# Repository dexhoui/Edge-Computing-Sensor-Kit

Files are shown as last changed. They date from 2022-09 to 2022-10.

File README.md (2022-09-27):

# **ECSK:** **E**deg **C**omputing **S**ensor **K**it
**Editor:** Bohao Chu, **Date:** 09.09.2022, **Email:** bohao.chu@qq.com

**Supervisor:**  Fuyin Wei, Fei Xiang, Bernd Noche

## **BASIC**
`git clone --recurse-submodules https://github.com/dexhoui/Edge-Computing-Sensor-Kit.git ./`
> git clone --recurese-submodules = git submodule init && git submodule update

`git submodule update --remote` update submodule from branch.

## **INTRODUCTION**
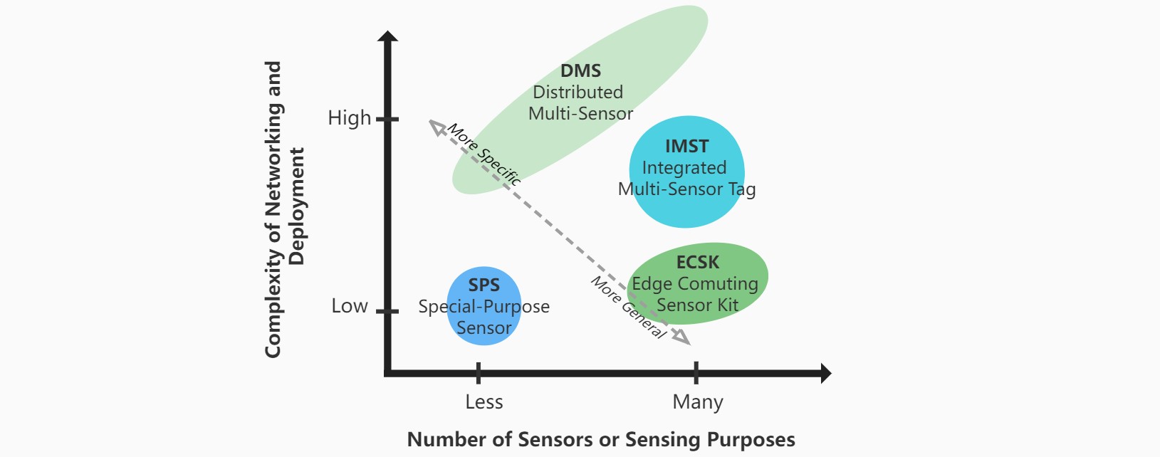
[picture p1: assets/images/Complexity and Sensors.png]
CM4 IO Board

In traditional IoT scenarios, **Specific-Purpose Sensor (SPS)** or **Distributed Multi-Sensor (DMS)** are usually deployed directly on different locations or objects to sense diverse purposes, However, the number of sensing purposes always conflict with the complexity of networking and deployment. **Integrated Multi-Sensor Tag (IMST)** alleviates this problem, such as Texas Instruments <i>SimpleLink SensorTag</i> and Laput's <i>Synthetic Sensors</i>, with multiple sensors integrated on a small board to indirectly monitor a large context,  without direct instrumentation of objects. But due to the limited computing power of IMST, a large amount of raw data still needs to be sent to the remote server for processing through wireless technologies such as <i>Bluetooth</i> or <i>WiFi</i> , which may lead to processing delays, data leakage or intrusion.

In this work, we explore the concept of **Edge Computing Senosr Kit (ECSK)** based on the former work. We designed a new type of hardware that integrates several different types of sensors, including a camera and a microphone, on a small board, while adding a powerful processor and tpu, which allows algorithmic models and applications to run directly on the it instead of on a remote server. Each sensor has a task channel of its own, and multiple sensors can independently perform data sampling and feature extraction with concurrency. Feature data from different sensor channels are used to achieve real-time recognition of general activities in the environment (e.g., robotic arm movement) by a **Machine Learning (ML)** based multi-sensor **Information Fusion** algorithm. 

## **HARDWARE**
We designed a new type of hardware that integrates several different types of sensors, including a camera and a microphone, on a small board, while adding a powerful processor and tpu, which allows algorithmic models and applications to run directly on the it instead of on a remote server.

Enter our <a href="./hardware/">Hardware Folder</a> to konw how to use it
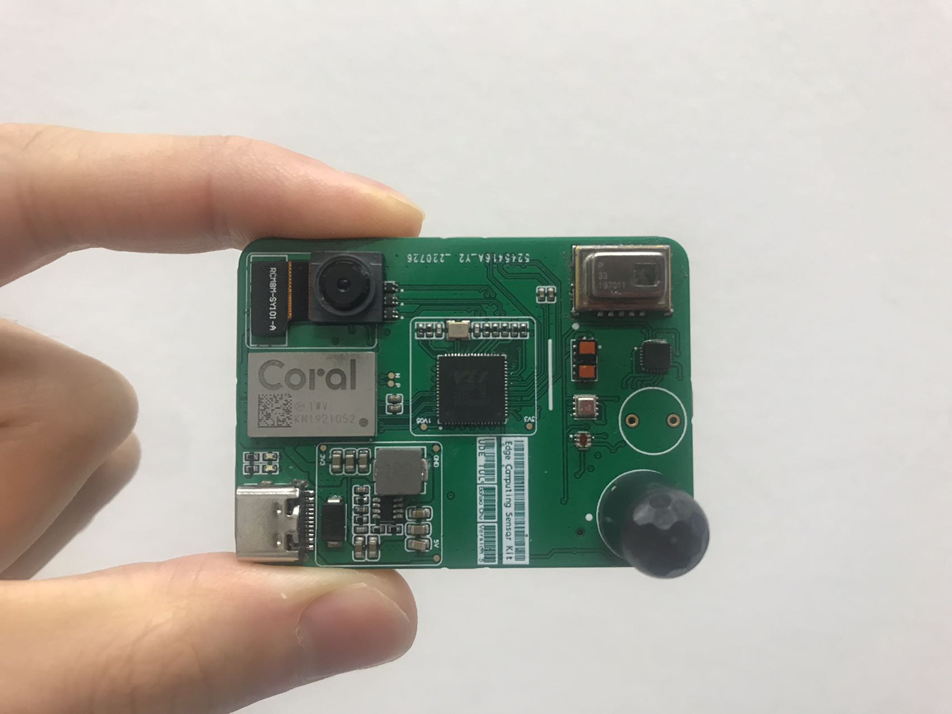
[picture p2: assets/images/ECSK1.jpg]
ECSK


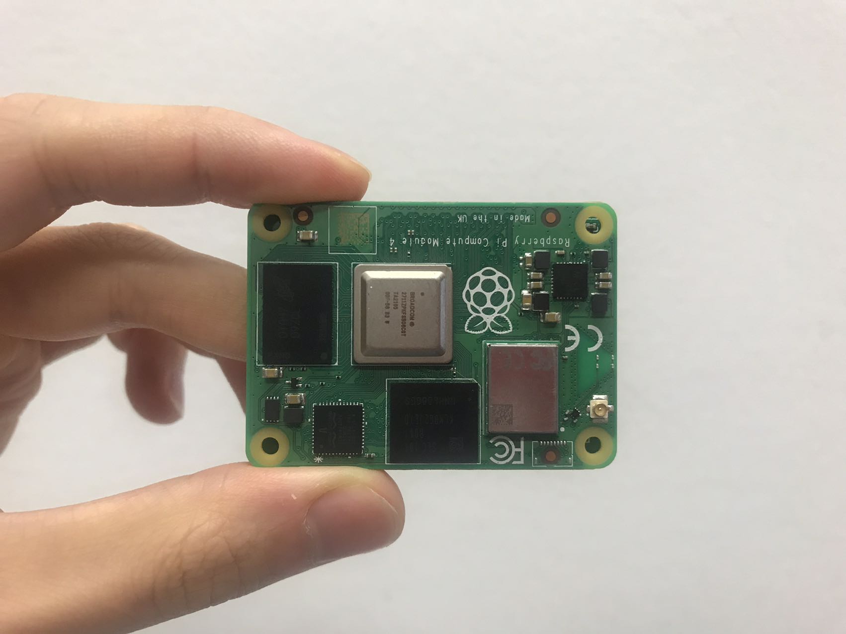
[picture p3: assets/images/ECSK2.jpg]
ECSK

<table border="1" style="text-align: center;">
    <tr>
        <td><b>Module</b></td>
        <td><b>Model</b></td> 
        <td><b>Protocol</b></td>
        <td><b>Frequency</b></td> 
        <td><b>Channel</b></td>
        <td><b>Description</b></td>
    </tr>
    <tr>
        <td><a href="https://coral.ai/products/accelerator-module">Coral</a></td>
        <td>G313</td> 
        <td>USB3.0</td> 
        <td>4TOPS</td>
        <td>1</td>
        <td>The Accelerator Module is a surface-mounted module that includes the Edge TPU and its own power control. It provides accelerated inferencing for TensorFlow Lite models on your custom PCB hardware.</td>
    </tr>
    <tr>
        <td>CM4</td>
        <td>ARM</td> 
        <td>/</td> 
        <td>Foo</td>
        <td>Foo</td>
        <td>/</td>
    </tr>
    <tr>
        <td>Microphone</td>
        <td><a href="https://learn.adafruit.com/adafruit-i2s-mems-microphone-breakout/raspberry-pi-wiring-test">INMP441</a></td> 
        <td>I2S</td> 
        <td>15K</td>
        <td>1</td>
        <td>1</td>
    </tr>
    <tr>
        <td>Motion Processing Unit</td>
        <td><a href="https://invensense.tdk.com/products/motion-tracking/9-axis/mpu-9250/">MPU9250</a></td> 
        <td>I2C</td> 
        <td>1K</td>
        <td>3</td>
        <td>The MPU-9250 is the company’s second generation 9-axis Motion Processing Unit™ for smartphones, tablets, wearable sensors, and other consumer markets.</td>
    </tr>
    <tr>
        <td>Laser</td>
        <td><a href="https://www.sparkfun.com/products/14722">VL53L1X</a></td> 
        <td>I2C</td> 
        <td>20</td>
        <td>1</td>
        <td>The MPU-9250 is the company’s second generation 9-axis Motion Processing Unit™ for smartphones, tablets, wearable sensors, and other consumer markets.</td>
    </tr>
    <tr>
        <td>EYE</td>
        <td><a href="https://www.sparkfun.com/products/14607">AMG8833</a></td> 
        <td>I2C</td> 
        <td>20</td>
        <td>1</td>
        <td>The MPU-9250 is the company’s second generation 9-axis Motion Processing Unit™ for smartphones, tablets, wearable sensors, and other consumer markets.</td>
    </tr>
    <tr>
        <td>BME</td>
        <td><a href="https://www.raspberrypi-spy.co.uk/2016/07/using-bme280-i2c-temperature-pressure-sensor-in-python/">BME280</a></td> 
        <td>I2C</td> 
        <td>20</td>
        <td>1</td>
        <td>The MPU-9250 is the company’s second generation 9-axis Motion Processing Unit™ for smartphones, tablets, wearable sensors, and other consumer markets.</td>
    </tr>
    <tr>
        <td>Color</td>
        <td><a href="https://www.sparkfun.com/products/12829">ISL29125</a></td> 
        <td>I2C</td> 
        <td>20</td>
        <td>1</td>
        <td>The MPU-9250 is the company’s second generation 9-axis Motion Processing Unit™ for smartphones, tablets, wearable sensors, and other consumer markets.</td>
    </tr>
    <tr>
        <td>ADC</td>
        <td><a href="https://www.sparkfun.com/products/15334">ADS1015</a></td> 
        <td>ADC</td> 
        <td>3.3K</td>
        <td>1</td>
        <td>The MPU-9250 is the company’s second generation 9-axis Motion Processing Unit™ for smartphones, tablets, wearable sensors, and other consumer markets.</td>
    </tr>
    <tr>
        <td>PIR</td>
        <td><a href="https://eu.mouser.com/ProductDetail/Panasonic-Industrial-Devices/AMN21111?qs=mTeSeKeuVA47b9orPGfrSw%3D%3D">AMN2111J</a></td> 
        <td>ADC</td> 
        <td>3.3K</td>
        <td>1</td>
        <td>The MPU-9250 is the company’s second generation 9-axis Motion Processing Unit™ for smartphones, tablets, wearable sensors, and other consumer markets.</td>
    </tr>
    <tr>
        <td>EMI</td>
        <td><a href="https://www.mouser.de/ProductDetail/Bourns/RLB0913-104K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">100MH</a></td> 
        <td>ADC</td> 
        <td>3.3K</td>
        <td>1</td>
        <td>The MPU-9250 is the company’s second generation 9-axis Motion Processing Unit™ for smartphones, tablets, wearable sensors, and other consumer markets.</td>
    </tr>
    <tr>
        <td>Camera</td>
        <td><a href="https://www.raspberrypi.com/products/camera-module-v2/">IMX219</a></td> 
        <td>CSI</td> 
        <td>80</td>
        <td>1</td>
        <td>The MPU-9250 is the company’s second generation 9-axis Motion Processing Unit™ for smartphones, tablets, wearable sensors, and other consumer markets.</td>
    </tr>
</table>

## **SOFTWARE**
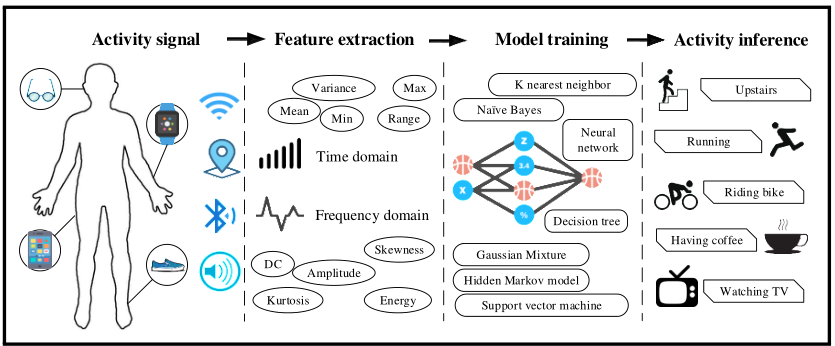
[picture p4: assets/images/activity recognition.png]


## **SENSOR EDGE**
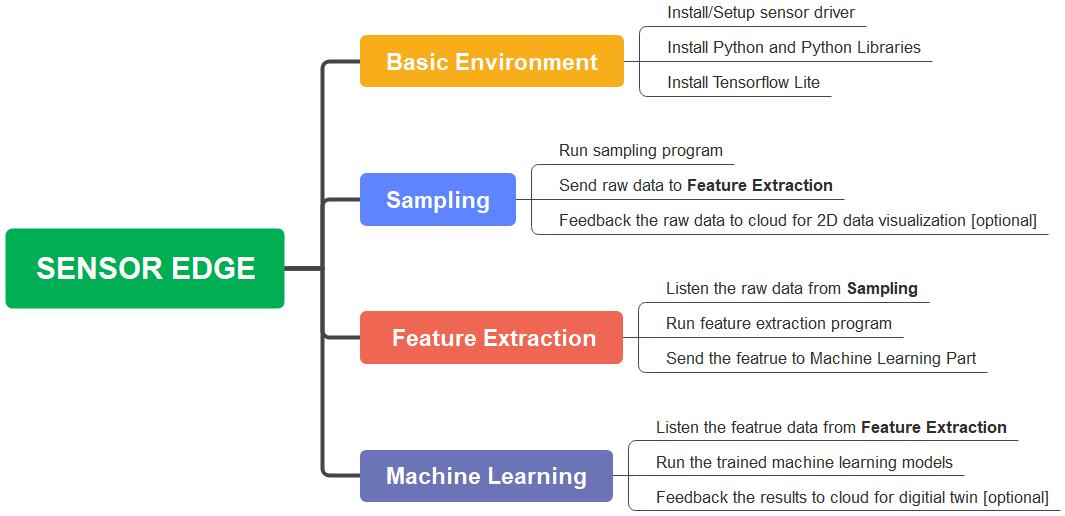
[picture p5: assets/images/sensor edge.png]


## **SENSOR SERVER**
ECSK

## **SENSOR APP**
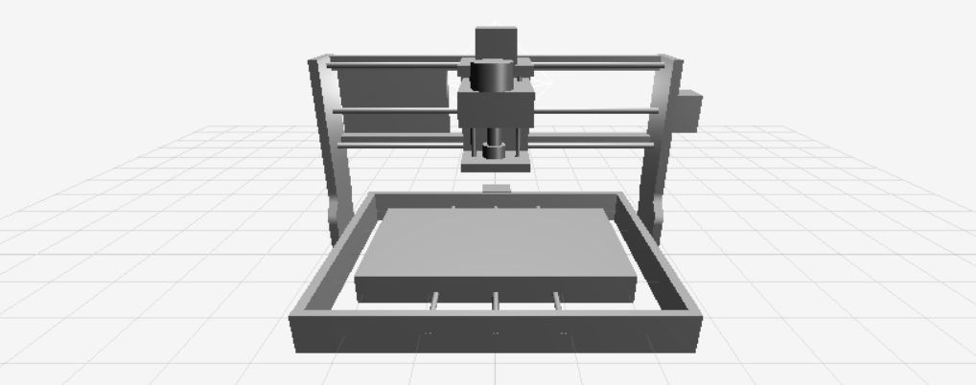
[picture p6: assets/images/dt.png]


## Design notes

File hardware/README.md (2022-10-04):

# **Hardware**
**Editor:** Bohao Chu, **Date:** 23.09.2022, **Email:** bohao.chu@qq.com

**Supervisor:**  Fuyin Wei, Fei Xiang, Bernd Noche

The **Edge Computing Sensor Kit Hardware** is consist of two parts, **Compute Module 4** and **Sensor Kit**. The Compute Module 4 can be bought in stores, and the Sensor Kit can be got via PCB Producer by providing our PCB file.

We designed our Sensor Kit via Altium Designer 22,  Without going into too much detail about the design of the PCB, I have made the  [source project](/hardware/printed%20circuit%20board/) available.

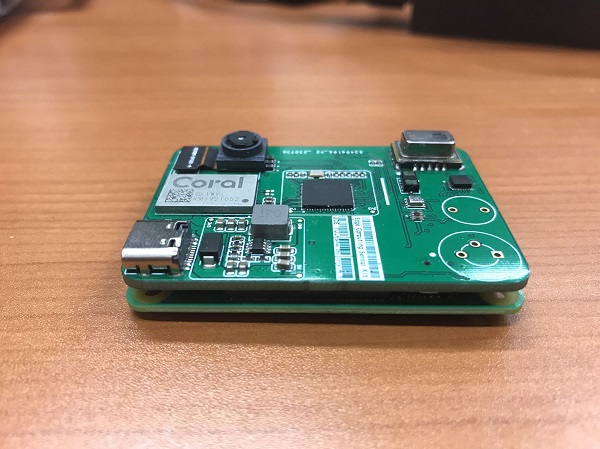
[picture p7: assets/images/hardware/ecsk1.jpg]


## **Compute Module 4**
In this chapter, I will discribe how to use it. 
[More information about Compute Module 4](https://www.raspberrypi.com/products/compute-module-4/?variant=raspberry-pi-cm4001000)

### **A. Flashing new OS ot Compute Module 4 eMMC**
We have to use an io board for flashing operation system. The requirementes for flashing the Compute Module 4 eMMC as follows:

- [Compute Module 4](https://www.raspberrypi.com/products/compute-module-4/?variant=raspberry-pi-cm4001000)
- [IO Board](https://www.waveshare.com/wiki/CM4-IO-BASE-A) ( other io boards are also available. )
- [Windows Installer](https://github.com/raspberrypi/usbboot/raw/master/win32/rpiboot_setup.exe) ( download it and insatll it, it may need to wait a while.)
- [Raspberry Pi Imager](https://downloads.raspberrypi.org/imager/imager_latest.exe)( download it and insatll it. )

#### **A1. Install Compute Module 4 on IO Board**
We used [Waveshare CM4 IO Board](https://www.waveshare.com/wiki/CM4-IO-BASE-A) as our IO board.
Ensure the Compute Module is fitted correctly installed on the IO board. It should lie flat on the IO board.

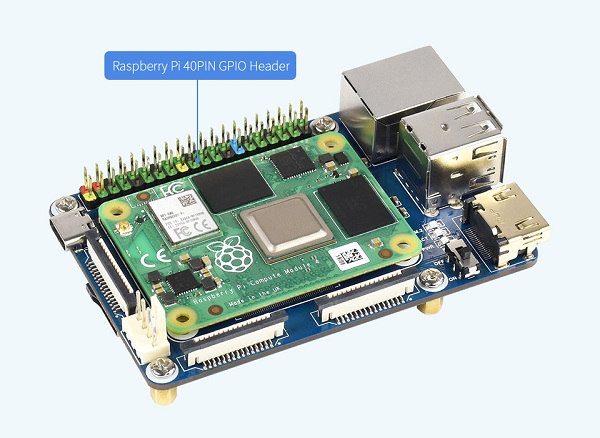
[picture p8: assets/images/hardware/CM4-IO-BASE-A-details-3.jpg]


#### **A2. Setup IO Board to USB model**
After the CM4 was installed on the IO Board, we should set IO Board to USB model by setting the switch to **ON**. Then plug your host PC USB into the USB SLAVE port. Supply power to the board.

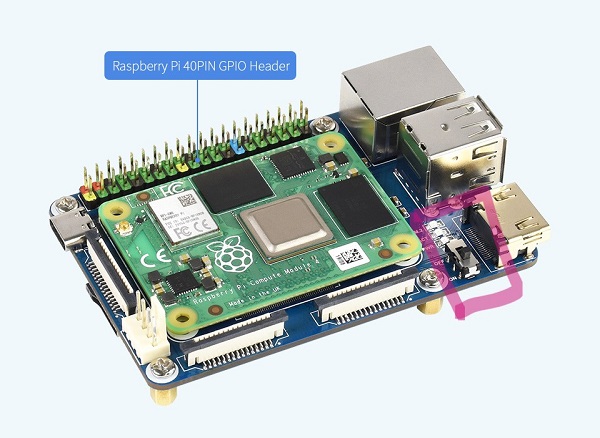
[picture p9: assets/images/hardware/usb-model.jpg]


#### **A3. Open rpiboot on windows**
This software is used to install the drivers and boot tool. After a few seconds, the Compute Module eMMC will pop up under Windows as a disk (USB mass storage device).

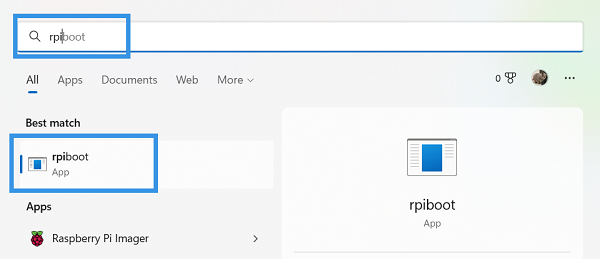
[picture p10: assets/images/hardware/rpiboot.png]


It may need to **wait a while**. *If you get stuck here, unplug the USB and then plug it into the PC again.*

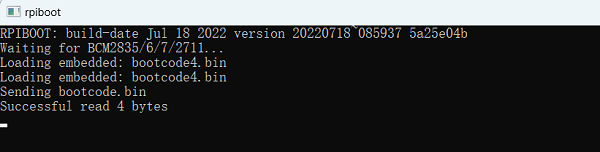
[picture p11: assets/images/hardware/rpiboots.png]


Then the CM4 will pop under windows as a **disk**.

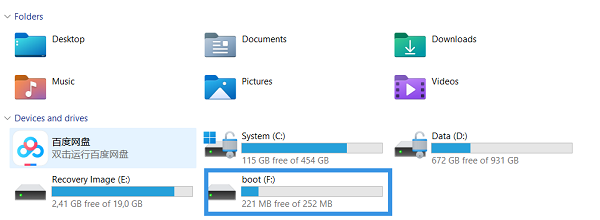
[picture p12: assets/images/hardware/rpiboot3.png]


#### **A4. Open RPI Imager on windows**
First, click the **CHOOSE OS** button, then select the **Raspberry Pi OS(other)** button, then choose the **Raspberry Pi OS(64-bit)** or **Raspberry Pi OS Lite(64-bit)**. Here I choosed the **Raspberry Pi OS(64-bit)** without Deskpot.

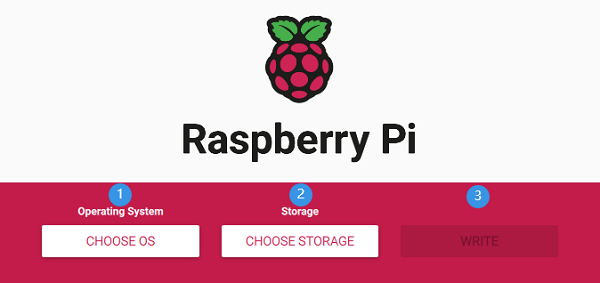
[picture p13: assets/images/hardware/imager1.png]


Second, click the **CHOOSE STORAGE**  button, then choose **RPI-MSD-0001** item.

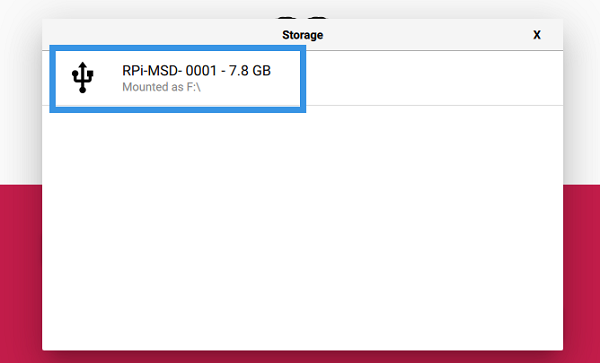
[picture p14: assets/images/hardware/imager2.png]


Third, click the **Setting**  button.
1. Select **Set hostname** and input "sensor".
2. Select **Enable SSH** and **use password authentication**.
3. Select **Set username and password**. set username to "pi", password to "123456". 
4. **Configure wireless LAN**, input name and password of WiFi. Set wireless LAN country as DE(Germany).
5. Select **Set locale settings**, set Time zone to "Europe/Berlin", Keyboard layout to "us".
6. Select **Eject media when finished** and **Enable telemetry**.

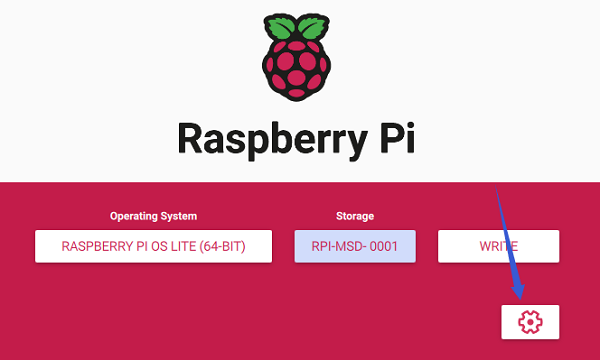
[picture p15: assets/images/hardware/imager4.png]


Finally, Click the **WRITE** button and choose **YES**, then wait a while.

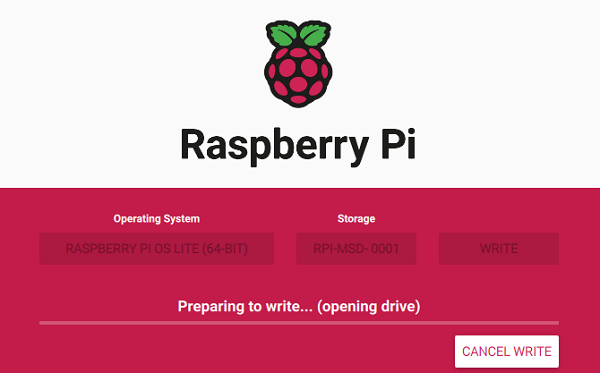
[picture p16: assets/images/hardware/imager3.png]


## **Sensor Kit**
After the OS was flashed into CM4, then uninstall CM4 from the io board, and install it on our edge computing sensor kit. Then supply 5V/3A (Not less than 2A) power to our Sensor Kit.

### **A. Config the WiFi**
We did not add the ethernet port to our sensor kit due to the space limitation and the Internet is not necesarry, but you can use the WiFi of CM4 to connect the Internet. You can use this way to change the WiFi SSID and WiFi Password so that the ECSK can be applied on anywhere with wifi.

1. Install the CM4 on IO board.

2. Setup IO Board to USB model and connect the USB to the PC, and then supply power to the IO Board.

3. Open rpiboot on windows, the CM4 will pop up under Windows as a disk. 

4. Enter this disk and make a new file named "wpa_supplicant.conf", and edit it with the following content.
>
    ctrl_interface=DIR=/var/run/wpa_supplicant GROUP=netdev
    update_config=1
    network={
        ssid="WiFi SSID"
        psk="WiFi Password"
    }
>

5. Then install CM4 on oure Sensor Kit and start up. After a while, it will automatically connect to the WiFi you have configured.

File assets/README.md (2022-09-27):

# ASSETS
**Editor:** Bohao Chu, **Date:** 24.09.2022, **Email:** bohao.chu@qq.com

**Supervisor:**  Fuyin Wei, Fei Xiang, Bernd Noche

## Images

The most of image in this project will be uploaded, but the most videos in this porject will not be uploaded, you can find them in Google Driver. For more information, please contact Mr.Fei Xiang.

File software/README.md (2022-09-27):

# **Software**
**Editor:** Bohao Chu, **Date:** 20.09.2022, **Email:** bohao.chu@qq.com

**Supervisor:**  Fuyin Wei, Fei Xiang, Bernd Noche

The **Edge Computing Sensor Kit Software** is consist of three parts, **[Sensor Server](/software/sensor-server/)**, **[Sensor Edge](/software/sensor-edge/)**, and **[Sensor Application](/software/sensor-application/)**. 

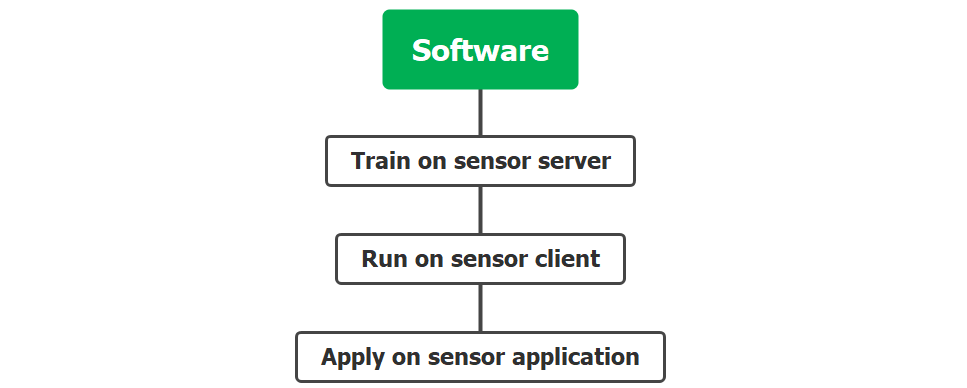
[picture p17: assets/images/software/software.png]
CM4 IO Board


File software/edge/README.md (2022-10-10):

# **SENSOR EDGE**
**Editor:** Bohao Chu, **Date:** 20.09.2022, **Email:** bohao.chu@qq.com

**Supervisor:**  Fuyin Wei, Fei Xiang, Bernd Noche

We need to do some initialization before runing our embedded program and machine learning model.
CM4 IO Board

## **BASIC ENVIRONMENT**
We recommend to install the following softwares before starting this section.

[Advance IP Scanner](https://download.radmin.com/download/files/Radmin_3.5.2.1_EN.zip) for getting the IP of ECSK.

[PUTTY](https://the.earth.li/~sgtatham/putty/latest/w64/putty-64bit-0.77-installer.msi) for connecting the ECSK via SSH. 

We recommend that the following two commands before executing any installation to ensure proper installation of the latest software.

- `sudo apt update`

- `sudo apt upgrade`

Install some common software. Some software requires your confirmation, so type Y when prompted.

- `sudo apt install git vim i2c-tools python3-pip portaudio19-dev libsndfile1`

Download source code.

- `git clone --branch edge https://github.com/dexhoui/Edge-Computing-Sensor-Kit.git ~/edge`

Install some python libraries.
- `sudo pip3 install smbus sparkfun-qwiic serial pyaudio matplotlib librosa tflite-runtime adafruit-python-shell`

### **A. Sensors Driver**
<table border="1" style="text-align: center;">
    <tr>
        <td><b>Module</b></td>
        <td><b>Model</b></td> 
        <td><b>Protocol</b></td>
        <td><b>Frequency</b></td> 
        <td><b>Channel</b></td>
        <td><b>Description</b></td>
    </tr>
    <tr>
        <td><a href="https://coral.ai/products/accelerator-module">Coral</a></td>
        <td>G313</td> 
        <td>USB3.0</td> 
        <td>4TOPS</td>
        <td>1</td>
        <td>The Accelerator Module is a surface-mounted module that includes the Edge TPU and its own power control. It provides accelerated inferencing for TensorFlow Lite models on your custom PCB hardware.</td>
    </tr>
    <tr>
        <td>CM4</td>
        <td>ARM</td> 
        <td>/</td> 
        <td>Foo</td>
        <td>Foo</td>
        <td>/</td>
    </tr>
    <tr>
        <td>Microphone</td>
        <td><a href="https://learn.adafruit.com/adafruit-i2s-mems-microphone-breakout/raspberry-pi-wiring-test">INMP441</a></td> 
        <td>I2S</td> 
        <td>15K</td>
        <td>1</td>
        <td>1</td>
    </tr>
    <tr>
        <td>Motion Processing Unit</td>
        <td><a href="https://invensense.tdk.com/products/motion-tracking/9-axis/mpu-9250/">MPU9250</a></td> 
        <td>I2C</td> 
        <td>1K</td>
        <td>3</td>
        <td>The MPU-9250 is the company’s second generation 9-axis Motion Processing Unit™ for smartphones, tablets, wearable sensors, and other consumer markets.</td>
    </tr>
    <tr>
        <td>Laser</td>
        <td><a href="https://www.sparkfun.com/products/14722">VL53L1X</a></td> 
        <td>I2C</td> 
        <td>20</td>
        <td>1</td>
        <td>The MPU-9250 is the company’s second generation 9-axis Motion Processing Unit™ for smartphones, tablets, wearable sensors, and other consumer markets.</td>
    </tr>
    <tr>
        <td>EYE</td>
        <td><a href="https://www.sparkfun.com/products/14607">AMG8833</a></td> 
        <td>I2C</td> 
        <td>20</td>
        <td>1</td>
        <td>The MPU-9250 is the company’s second generation 9-axis Motion Processing Unit™ for smartphones, tablets, wearable sensors, and other consumer markets.</td>
    </tr>
    <tr>
        <td>BME</td>
        <td><a href="https://www.raspberrypi-spy.co.uk/2016/07/using-bme280-i2c-temperature-pressure-sensor-in-python/">BME280</a></td> 
        <td>I2C</td> 
        <td>20</td>
        <td>1</td>
        <td>The MPU-9250 is the company’s second generation 9-axis Motion Processing Unit™ for smartphones, tablets, wearable sensors, and other consumer markets.</td>
    </tr>
    <tr>
        <td>Color</td>
        <td><a href="https://www.sparkfun.com/products/12829">ISL29125</a></td> 
        <td>I2C</td> 
        <td>20</td>
        <td>1</td>
        <td>The MPU-9250 is the company’s second generation 9-axis Motion Processing Unit™ for smartphones, tablets, wearable sensors, and other consumer markets.</td>
    </tr>
    <tr>
        <td>ADC</td>
        <td><a href="https://www.sparkfun.com/products/15334">ADS1015</a></td> 
        <td>ADC</td> 
        <td>3.3K</td>
        <td>1</td>
        <td>The MPU-9250 is the company’s second generation 9-axis Motion Processing Unit™ for smartphones, tablets, wearable sensors, and other consumer markets.</td>
    </tr>
    <tr>
        <td>PIR</td>
        <td><a href="https://eu.mouser.com/ProductDetail/Panasonic-Industrial-Devices/AMN21111?qs=mTeSeKeuVA47b9orPGfrSw%3D%3D">AMN2111J</a></td> 
        <td>ADC</td> 
        <td>3.3K</td>
        <td>1</td>
        <td>The MPU-9250 is the company’s second generation 9-axis Motion Processing Unit™ for smartphones, tablets, wearable sensors, and other consumer markets.</td>
    </tr>
    <tr>
        <td>EMI</td>
        <td><a href="https://www.mouser.de/ProductDetail/Bourns/RLB0913-104K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">100MH</a></td> 
        <td>ADC</td> 
        <td>3.3K</td>
        <td>1</td>
        <td>The MPU-9250 is the company’s second generation 9-axis Motion Processing Unit™ for smartphones, tablets, wearable sensors, and other consumer markets.</td>
    </tr>
    <tr>
        <td>Camera</td>
        <td><a href="https://www.raspberrypi.com/products/camera-module-v2/">IMX219</a></td> 
        <td>CSI</td> 
        <td>80</td>
        <td>1</td>
        <td>The MPU-9250 is the company’s second generation 9-axis Motion Processing Unit™ for smartphones, tablets, wearable sensors, and other consumer markets.</td>
    </tr>
</table>

#### **A1. Microphone Driver**

**First**, install INMP441 Driver, execute the following commands sequentially in Terminal.
1. `cd ~/edge/tools/ && sudo python3 i2smic.py`
2. Please type y when prompt `"Auto load module at boot"?`
3. Please type y when prompt `"REBOOT NOW? [Y/n]"`
4. Connect it again via ssh.

**Second**, Test the INMP441 Driver.
1. `arecord -l`
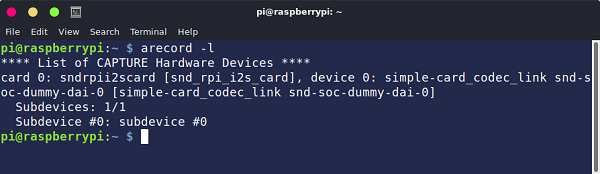
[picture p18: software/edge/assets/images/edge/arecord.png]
- 

2. `arecord -D plughw:0 -c1 -r 48000 -f S32_LE -t wav -V mono -v file.wav`
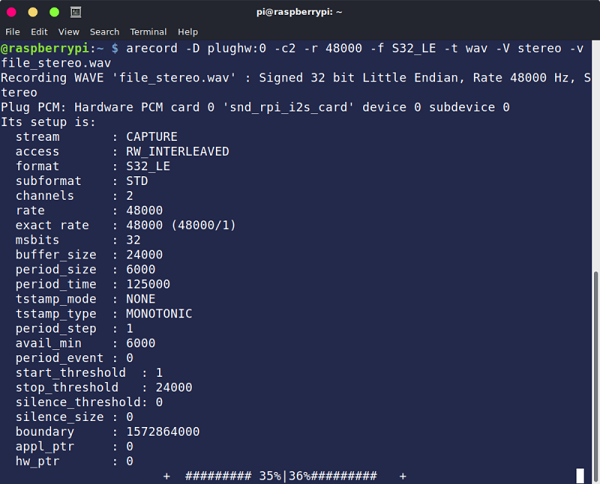
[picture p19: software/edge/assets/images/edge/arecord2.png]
- 

3. `rm file.wav`

4. `python3 ~/edge/source/drivers/micDriver.py`
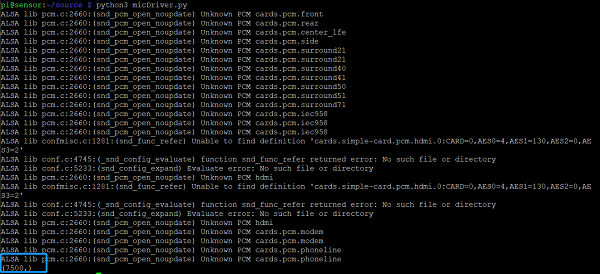
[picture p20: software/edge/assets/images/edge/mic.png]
MIC
- 

#### **A2. Motion Processing Unit**
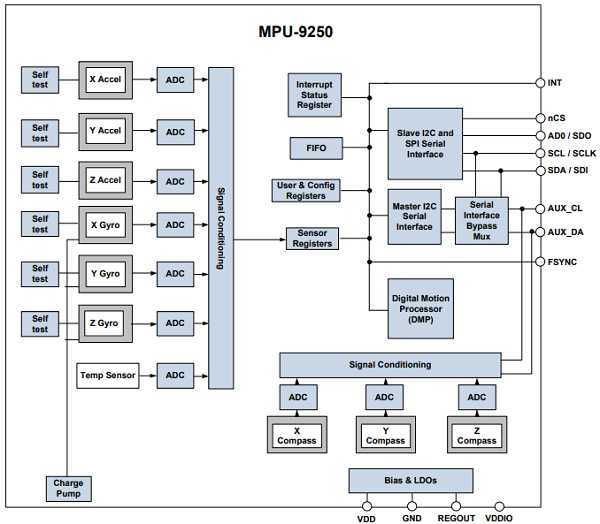
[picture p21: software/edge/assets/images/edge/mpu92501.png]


**First**, Open I2C1 interface of CM4.
1. `sudo raspi-config`
2. Select `3 Interface Options` and type *Enter* key.
3. Select `I5 I2C` and type *Enter* key.
4. Select `YES` via *Tab* Key
5. Select `Finish` via *Tab* Key
3. `sudo reboot` and then connect it again via ssh.

**Second**, Check the status of i2c1 and the device mount on it.

1. `i2cdetect -l` to show all i2c interfaces.

- CM4 IO Board

2. `i2cdetect -y 1` the show all device mount on i2c1 interface, the **0x68** is the address of MPU9250.

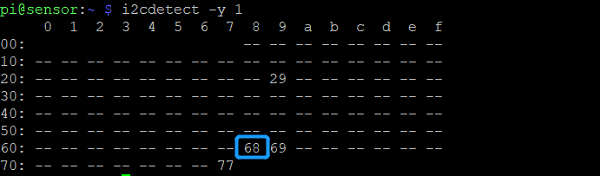
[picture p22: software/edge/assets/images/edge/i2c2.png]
- 

**Third**, test the driver of MPU9250.

1. `python3 ~/edge/source/drivers/mpuDriver.py`
- CM4 IO Board

[Not work for Magnetometer](https://github.com/kriswiner/MPU9250/issues/123)

#### **A3. Laser Distance**
**First**, Open I2C1 interface of CM4.

It has been opened in the above, no need to open it again. If there is no i2c-1, please operate again.

`i2cdetect -l` to show all i2c interfaces.

- CM4 IO Board

**Second**, Check the status of i2c1 and the device mount on it.
1. `i2cdetect -y 1` the show all device mount on i2c1 interface, the **0x29** is the address of VL53L1X.

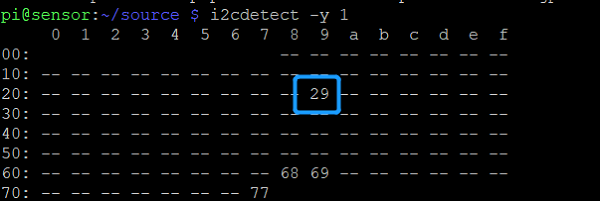
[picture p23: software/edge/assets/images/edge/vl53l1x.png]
- 

**Third**, test the driver of VL53L1X.

1. `python3 ~/edge/source/drivers/laserDriver.py`

- CM4 IO Board

#### **A4. EYE**
**First**, Open I2C1 interface of CM4.

It has been opened in the above, no need to open it again. If there is no i2c-1, please operate again.

1. `i2cdetect -l` to show all i2c interfaces.`
- CM4 IO Board

2. `i2cdetect -y 1` the show all device mount on i2c1 interface, the **0x69** is the address of AMG8833.
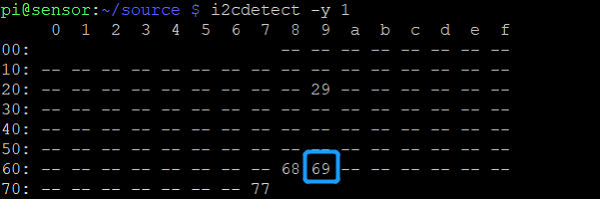
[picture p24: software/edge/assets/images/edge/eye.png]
- 

**Second**, test the driver of AMG8833.

1. `python3 ~/edge/source/drivers/eyeDriver.py`
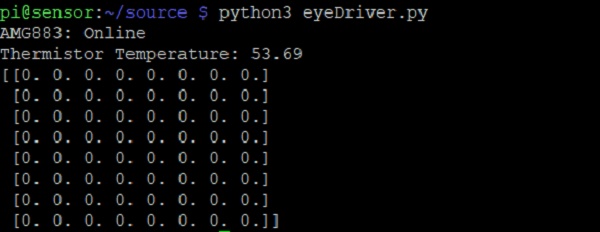
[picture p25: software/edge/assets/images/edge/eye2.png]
- 

#### **A5. BME**
**First**, Open I2C1 interface of CM4.

It has been opened in the above, no need to open it again. If there is no i2c-1, please operate again.

1. `i2cdetect -l` to show all i2c interfaces.`
- CM4 IO Board

2. `i2cdetect -y 1` the show all device mount on i2c1 interface, the **0x77** is the address of BME280.
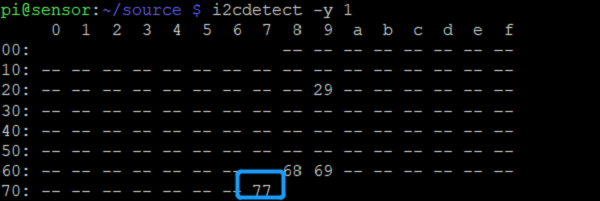
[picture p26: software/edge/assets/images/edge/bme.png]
- 

**Second**, test the driver of BME280.

1. `python3 ~/edge/source/drivers/bmeDriver.py`
- BME

#### **A6. Color**

**First**, Open I2C3 interface of CM4.
1. `sudo vim /boot/config.txt`
2. add `dtoverlay=i2c3,pin_4_5=1` below *# uncommet some or all of these to enable the opetional optional hardware interfaces*.
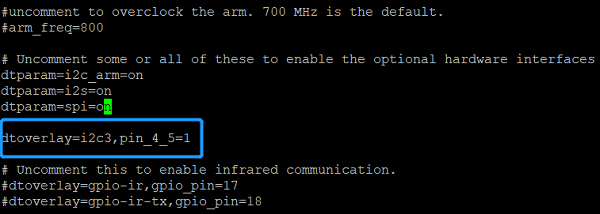
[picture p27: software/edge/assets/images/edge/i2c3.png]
- 
3. save it and execut the command `sudo reboot` to reboot the ECSK.

**Second**, Check the status of i2c3 and the device mount on it.

1. `i2cdetect -l` to show all i2c interfaces.

- CM4 IO Board

2. `i2cdetect -y 3` the show all device mount on i2c3 interface, the **0x44** is the address of ISL29125.

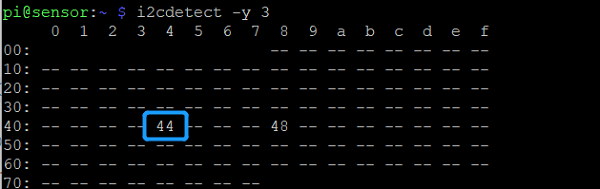
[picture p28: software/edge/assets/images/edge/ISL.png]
- 

**Third**, test the driver of ISL29125.

1. `python3 ~/edge/source/drivers/islDriver.py`
- CM4 IO Board

#### **A7. ADC**
**First**, Open I2C3 interface of CM4.

It has been opened in the above, no need to open it again. If there is no i2c-3, please operate again.

1. `i2cdetect -l` to show all i2c interfaces.`
- CM4 IO Board

2. `i2cdetect -y 3` the show all device mount on i2c1 interface, the **0x48** is the address of ADC.
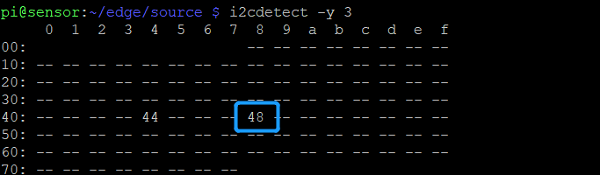
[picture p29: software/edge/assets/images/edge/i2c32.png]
- 

**Second**, Check the status of i2c3 and the device which mounted on it.

*Actually, we added two sensors AMN21111 and 100H Inductors on ADC, but we did not use them in this version. We will extent them in next version.*

#### **A8. Camera**
**First**, Open CSI1 interface of CM4.

1. `sudo vim /boot/config.txt`
2. add `dtoverlay=imx219,cam1` below *# Automatically load overlays for detected cameras*.
- 
3. save it and execut the command `sudo reboot` to reboot the ECSK.

**Second**, Check the status of CSI1.
1. `i2cdetect -l`
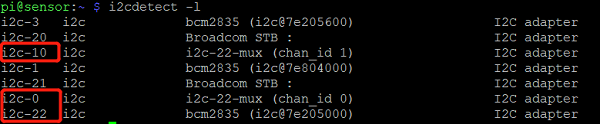
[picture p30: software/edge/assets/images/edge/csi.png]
- 

2. `libcamera-hello --list`
- 

**Third**, make a picture.
1. `libcamera-jpeg -o test.jpg`
- 
- 

*You can use SFTP software to download the picture from ECCSK, e.g. [FileZilla](https://filezilla-project.org/), the SFTP Port is 22. You can also use other software, e.g. [Pycharm](https://www.jetbrains.com/pycharm/). Here we do not intruduce how to use SFTP, please Google it yourself.*

## **SAMPLING**

In this section, we introduce how to use **ECSK** to sample the raw data for model training. Please ignore this section If you just want to use the sampled raw data or trained models. Because we have already sampled the raw data and trained some models for some scenes, e.g. CNC machine, Office, BOH machine, Logistics Car, so you can use these raw directly to train you model, and then deploy these model on you ECSK.

Here, we strongly recommend [Pycharm](https://www.jetbrains.com/pycharm/download/#section=windows) to develop edge project, and we do not make too much of the use of Pycharm, please Google it yourself.

### **Download source code to PC**
1. Create a empty folder named ECSK on PC in your perferred location. enter the floder and open the **Git Bash Here** by right click, *(make sure that you have already installed the **git**)*.
- git

2. `git clone https://github.com/chubohao/edge-computing-sensor-kit.git ./` please ignore thie step if you have already downloaded it.
- git

3. Use pycharm to open its subfolder *"ecsk/software/edge/"*
- pycharm

4. Make the configuration for deployment.
- Tools-> Deployment-> Configuration

- pycharm
- Click "**+**", and select SFTP, and input the alias, here I inputted "**edge**".
- pycharm
- SSH configuration
- pycharm
- Input the *host ip*, *username*, and *password* of ECSK, and test connnection.
- pycharm
- In **Connection** page, click **Autodetect**.
- pycharm
- In **Mappings** page, input */edge* to Deployment path.
- pycharm
- Finally, select **Automatic Upload(Always)**, then your code will automatically upload to ECSK after the code is changed.
- pycharm
- Open SSH tools of Pycharm/.
- pycharm
- Then you can use it to control your ECSK instead of PuTTY.
- pycharm

5. Config the scene information in the file of **source/arguments.py**, you should change the variable **dataset**, **activity**, and **duration** according your scenes.
- pycharm

6. Execute the sampling program, please make sure the activity is taking place in your scenario.
- `python3 ~/edge/source/sampling/sampling.py`
- pycharm

7. Download the data from ECSK for the next training.
- Tools-> Deployment-> Browse Remote Host
- pycharm
- In the ECSK, select the folder dataset, and downlaod form here.
- pycharm
- Then you can find them in you PC.
- pycharm

## WARNING
> ALSA lib pcm.c:2660:(snd_pcm_open_noupdate) Unknown PCM cards.pcm.rear
ALSA lib pcm.c:2660:(snd_pcm_open_noupdate) Unknown PCM cards.pcm.center_lfe
ALSA lib pcm.c:2660:(snd_pcm_open_noupdate) Unknown PCM cards.pcm.side
ALSA lib pcm.c:2660:(snd_pcm_open_noupdate) Unknown PCM cards.pcm.surround21
ALSA lib pcm.c:2660:(snd_pcm_open_noupdate) Unknown PCM cards.pcm.surround21
ALSA lib pcm.c:2660:(snd_pcm_open_noupdate) Unknown PCM cards.pcm.surround40
ALSA lib pcm.c:2660:(snd_pcm_open_noupdate) Unknown PCM cards.pcm.surround41
ALSA lib pcm.c:2660:(snd_pcm_open_noupdate) Unknown PCM cards.pcm.surround50
ALSA lib pcm.c:2660:(snd_pcm_open_noupdate) Unknown PCM cards.pcm.surround51
ALSA lib pcm.c:2660:(snd_pcm_open_noupdate) Unknown PCM cards.pcm.surround71
ALSA lib pcm.c:2660:(snd_pcm_open_noupdate) Unknown PCM cards.pcm.iec958
ALSA lib pcm.c:2660:(snd_pcm_open_noupdate) Unknown PCM cards.pcm.iec958
ALSA lib pcm.c:2660:(snd_pcm_open_noupdate) Unknown PCM cards.pcm.iec958
ALSA lib confmisc.c:1281:(snd_func_refer) Unable to find definition 'cards.simple-card.pcm.hdmi.0:CARD=0,AES0=4,AES1=130,AES2=0,AES3=2'
ALSA lib conf.c:4745:(_snd_config_evaluate) function snd_func_refer returned error: No such file or directory
ALSA lib conf.c:5233:(snd_config_expand) Evaluate error: No such file or directory
ALSA lib pcm.c:2660:(snd_pcm_open_noupdate) Unknown PCM hdmi
ALSA lib confmisc.c:1281:(snd_func_refer) Unable to find definition 'cards.simple-card.pcm.hdmi.0:CARD=0,AES0=4,AES1=130,AES2=0,AES3=2'
ALSA lib conf.c:4745:(_snd_config_evaluate) function snd_func_refer returned error: No such file or directory
ALSA lib conf.c:5233:(snd_config_expand) Evaluate error: No such file or directory
ALSA lib pcm.c:2660:(snd_pcm_open_noupdate) Unknown PCM hdmi
ALSA lib pcm.c:2660:(snd_pcm_open_noupdate) Unknown PCM cards.pcm.modem
ALSA lib pcm.c:2660:(snd_pcm_open_noupdate) Unknown PCM cards.pcm.modem
ALSA lib pcm.c:2660:(snd_pcm_open_noupdate) Unknown PCM cards.pcm.phoneline
ALSA lib pcm.c:2660:(snd_pcm_open_noupdate) Unknown PCM cards.pcm.phoneline

`sudo cp ~/edge/tools/alsa.conf /usr/share/alsa/`

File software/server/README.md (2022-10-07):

# **SERVER**
**Editor:** Bohao Chu, **Date:** 20.09.2022, **Email:** bohao.chu@qq.com

**Supervisor:**  Fuyin Wei, Fei Xiang, Bernd Noche

The **Edge Computing Sensor Kit SERVER** is consist of three parts, **[Sensor Server](/software/sensor-server/)**, **[Sensor Edge](/software/sensor-edge/)**, and **[Sensor Application](/software/sensor-application/)**.

CM CM4 IO Board

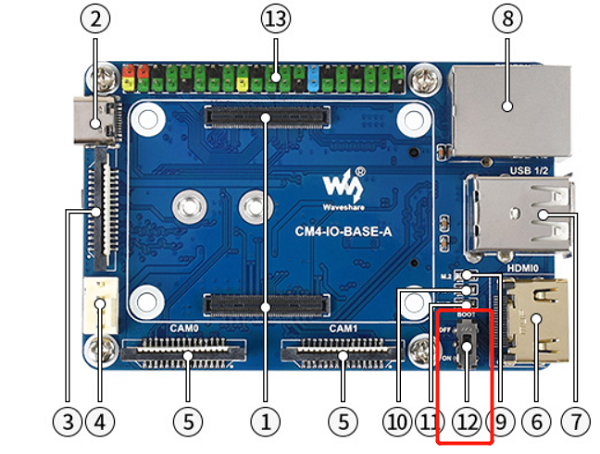
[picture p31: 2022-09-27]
assets/images/hardware/USB model.png

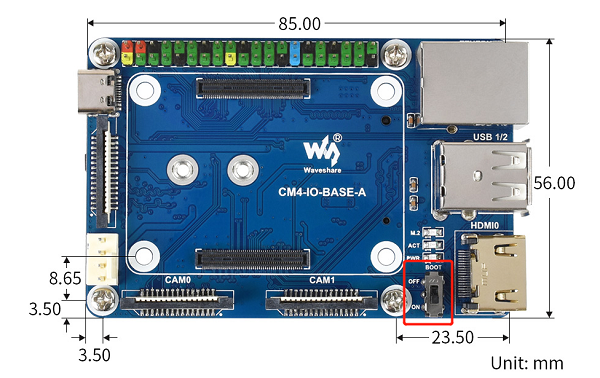
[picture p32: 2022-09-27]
assets/images/hardware/USB.png

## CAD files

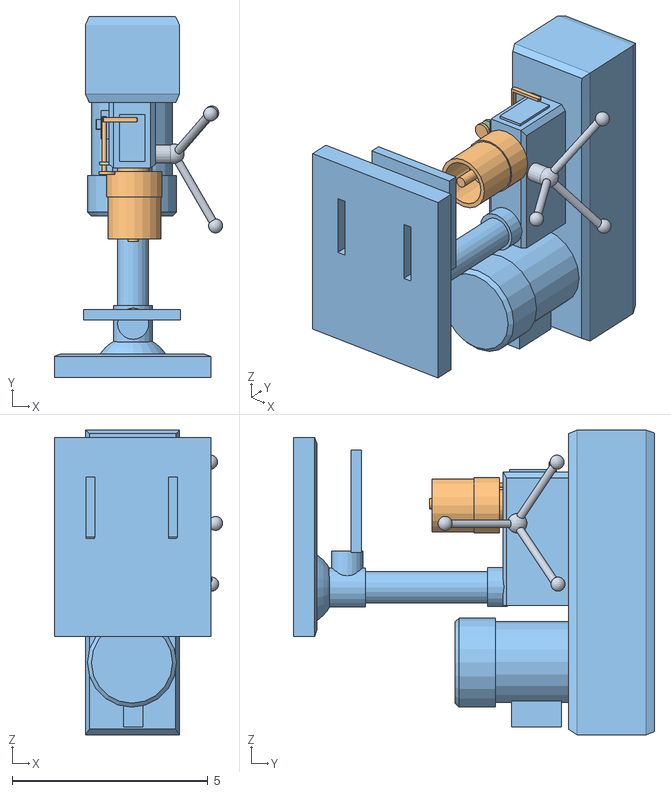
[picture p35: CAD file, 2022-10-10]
software/application/assets/model/350/350.obj
4.30 x 9.22 x 7.79
hand
spin
main
pasted__pasted__pCylinder7 pasted__group5 group25

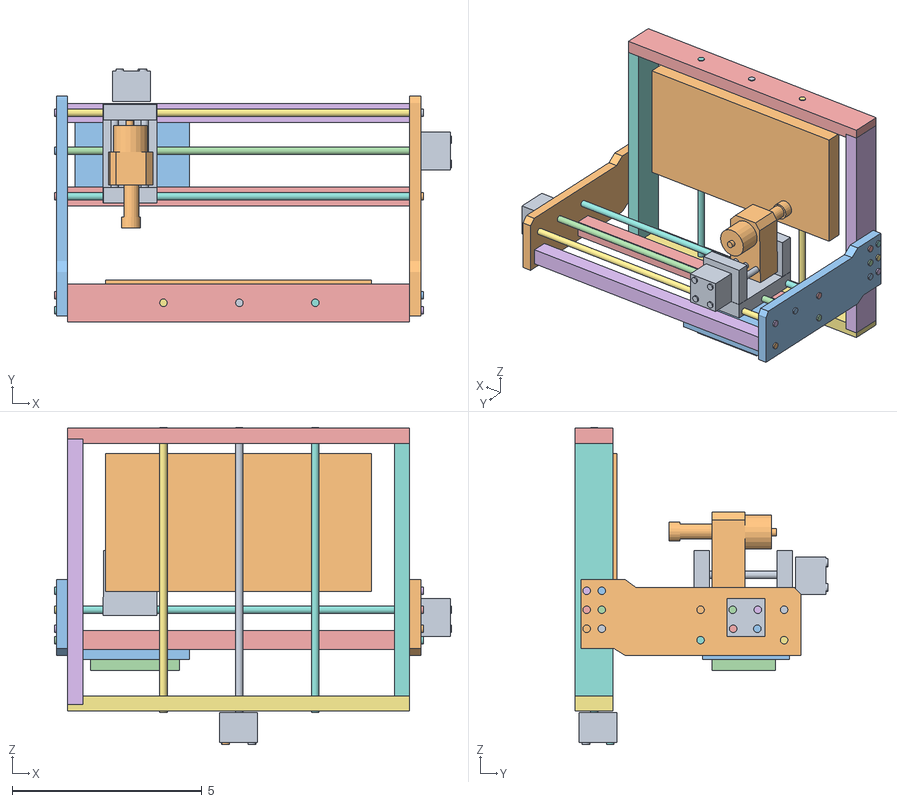
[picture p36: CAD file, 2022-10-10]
software/application/assets/model/cnc/cnc1.obj
10.5 x 6.65 x 8.35
pCube2
bottom
pCube7
pCylinder1
pCube9
pCube11
pCylinder5
pCylinder6
pCube12
pCylinder7
pCylinder8
pCylinder9
pCylinder10
pCylinder11
pCylinder12
pCylinder13
pCylinder14
pCylinder15
pCylinder16
pCylinder17
pCylinder18
pCylinder19
pCylinder20
pCylinder21
pCylinder22
pCylinder23
pCylinder24
pCylinder25
pCylinder26
pCylinder27
pCylinder34
pCylinder35
pCylinder36
pCylinder37
pCylinder38
pCylinder39
pCylinder40
pCylinder41
pCylinder46
pCylinder47
pCylinder48
pCube18
pCube19
pCube20
pCube21
pCube22
pCube23
pCube24
leftright
updown

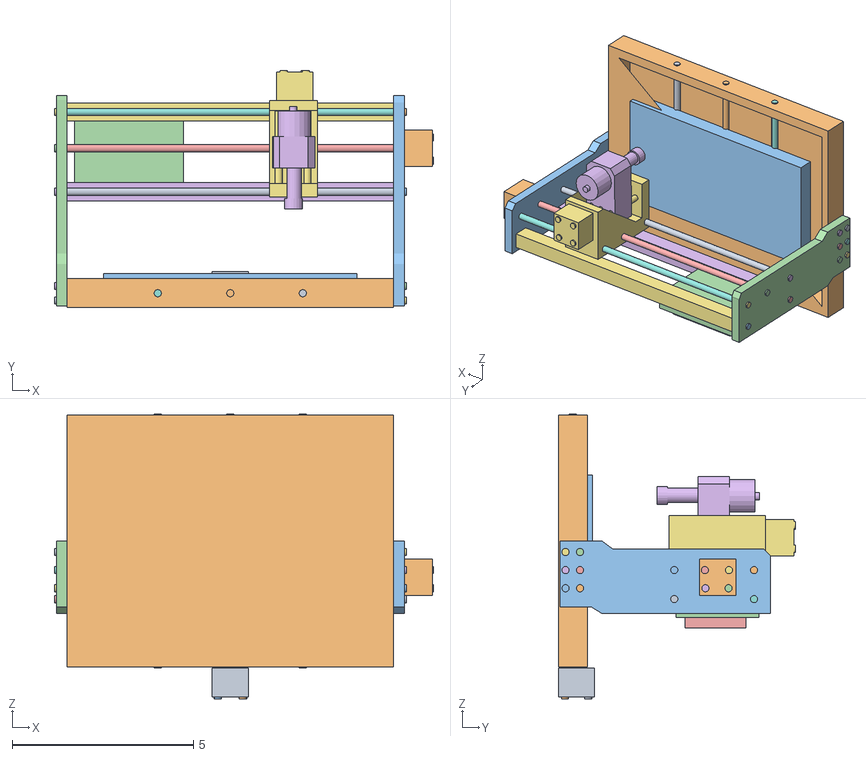
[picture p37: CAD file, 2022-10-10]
software/application/assets/model/cnc/cnc.obj
10.5 x 6.55 x 7.85
pCube2
pCube5
bottom
pCube7
pCylinder1
pCube9
pCube11
pCylinder5
pCylinder6
pCube12
pCylinder7
pCylinder8
pCylinder9
pCylinder10
pCylinder11
pCylinder12
pCylinder13
pCylinder14
pCylinder15
pCylinder16
pCylinder17
pCylinder18
pCylinder19
pCylinder20
pCylinder21
pCylinder22
pCylinder23
pCylinder24
pCylinder25
pCylinder26
pCylinder27
pCylinder34
pCylinder35
pCylinder36
pCylinder37
pCylinder38
pCylinder39
pCylinder40
pCylinder41
pCylinder46
pCylinder47
pCylinder48
pCube18
pCube19
pCube20
updown
leftright

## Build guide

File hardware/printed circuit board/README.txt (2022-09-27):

1. 最小内径0.2mm = 7.8 mil
2. 最小外径0.4mm = 15.7 mil
3. 最小线距3.5mil
4. 焊盘边缘到线距离5mil
5. 走线和焊盘距板边距离>=0.3mm = 12
6. 过孔与过孔之间的距离 10mil
100欧姆阻抗
线距5mil, 线宽4mil, 误差0.15mm=5.9mil

90欧姆阻抗
线距5mil, 线宽5.17mil, 误差0.1mm=3.9mil

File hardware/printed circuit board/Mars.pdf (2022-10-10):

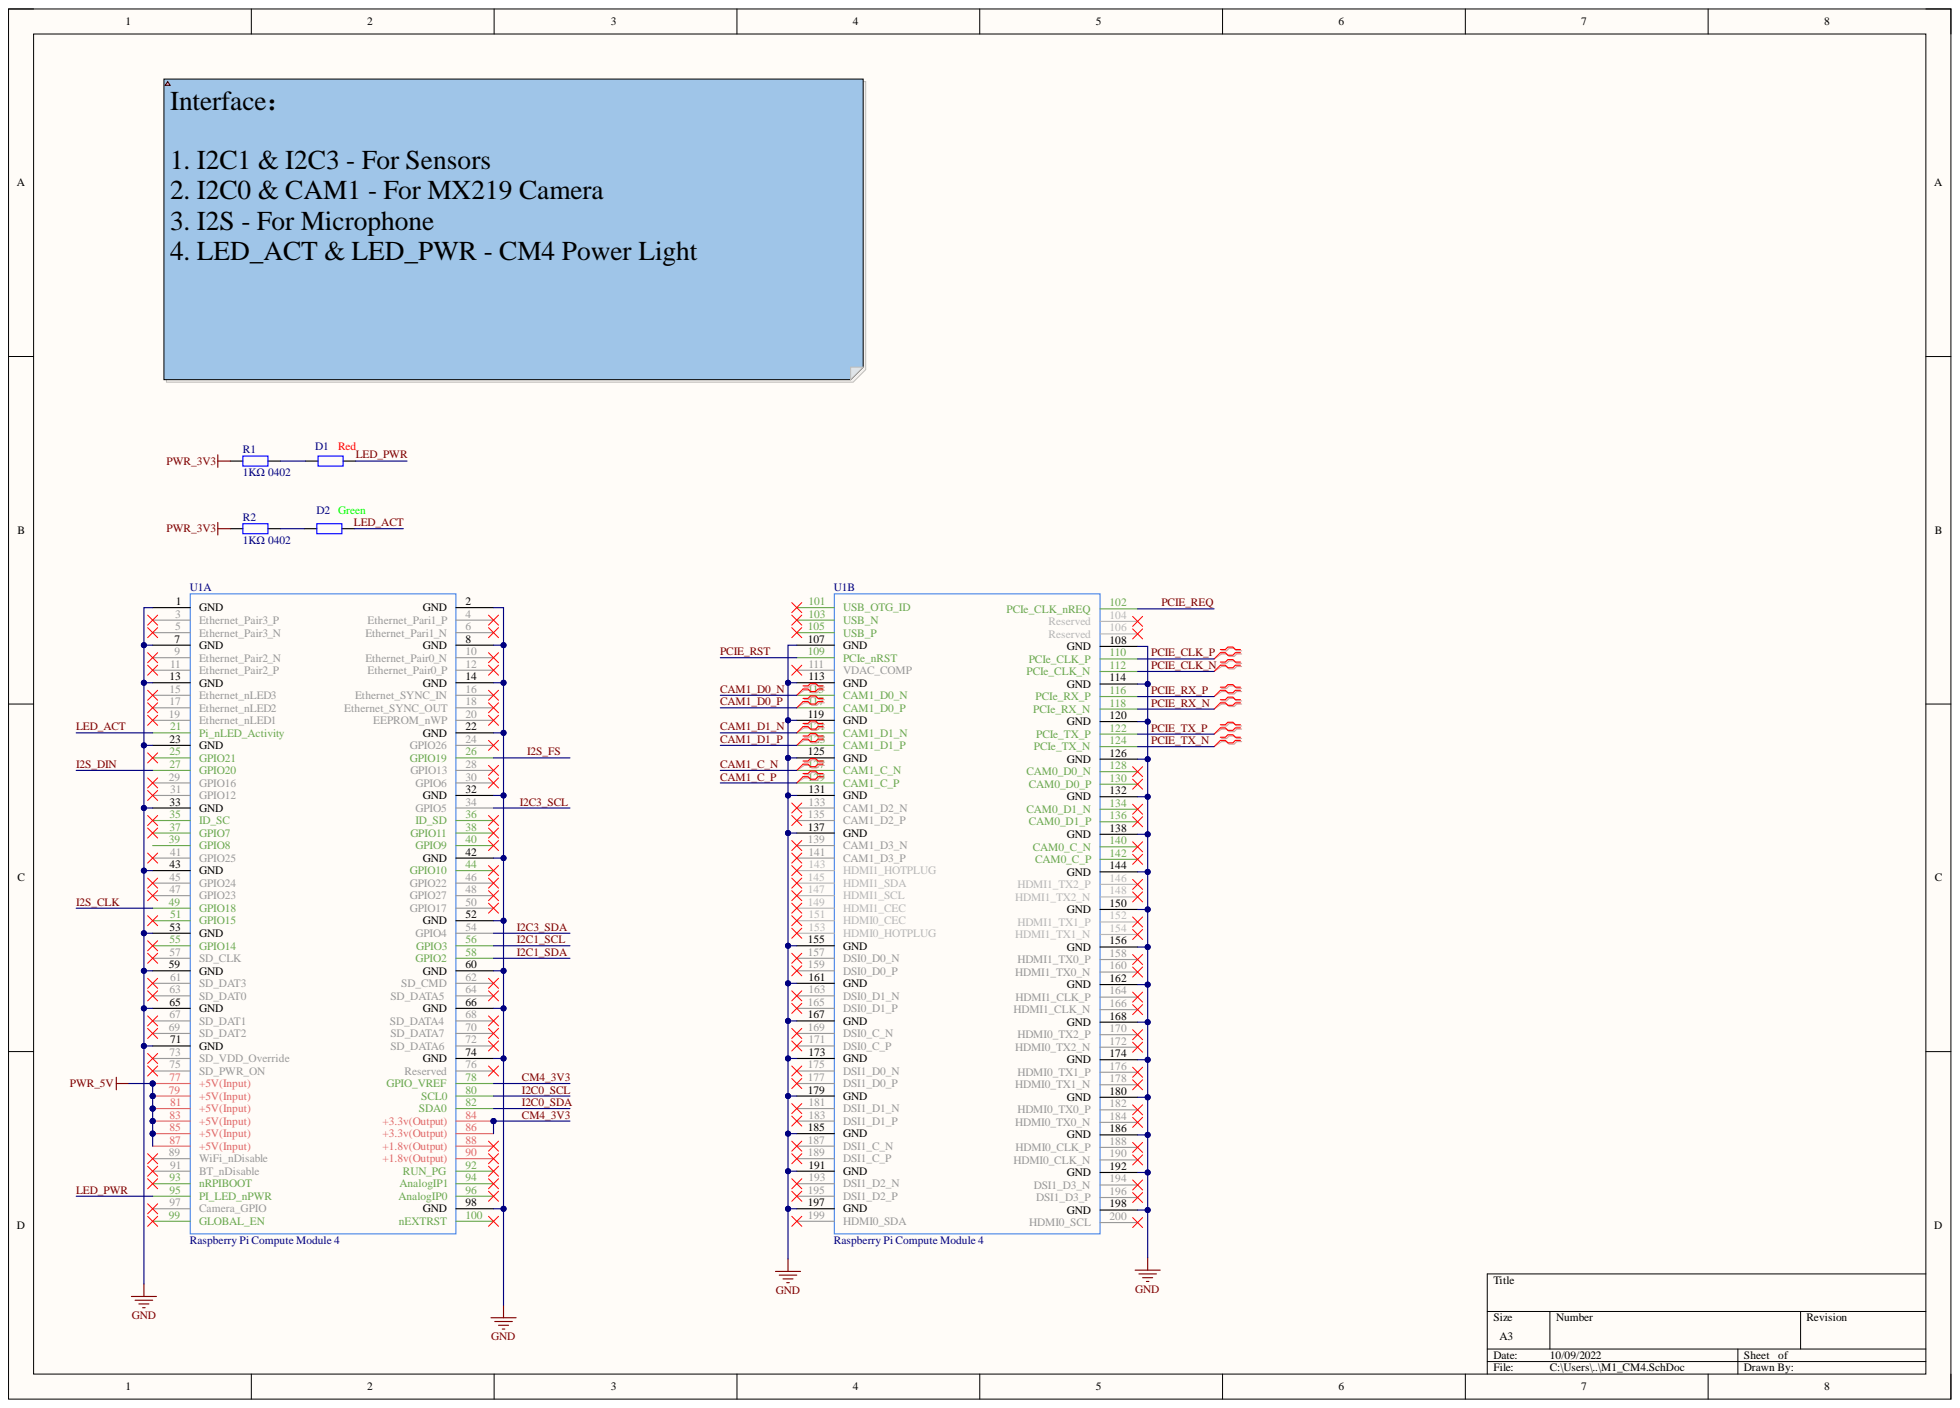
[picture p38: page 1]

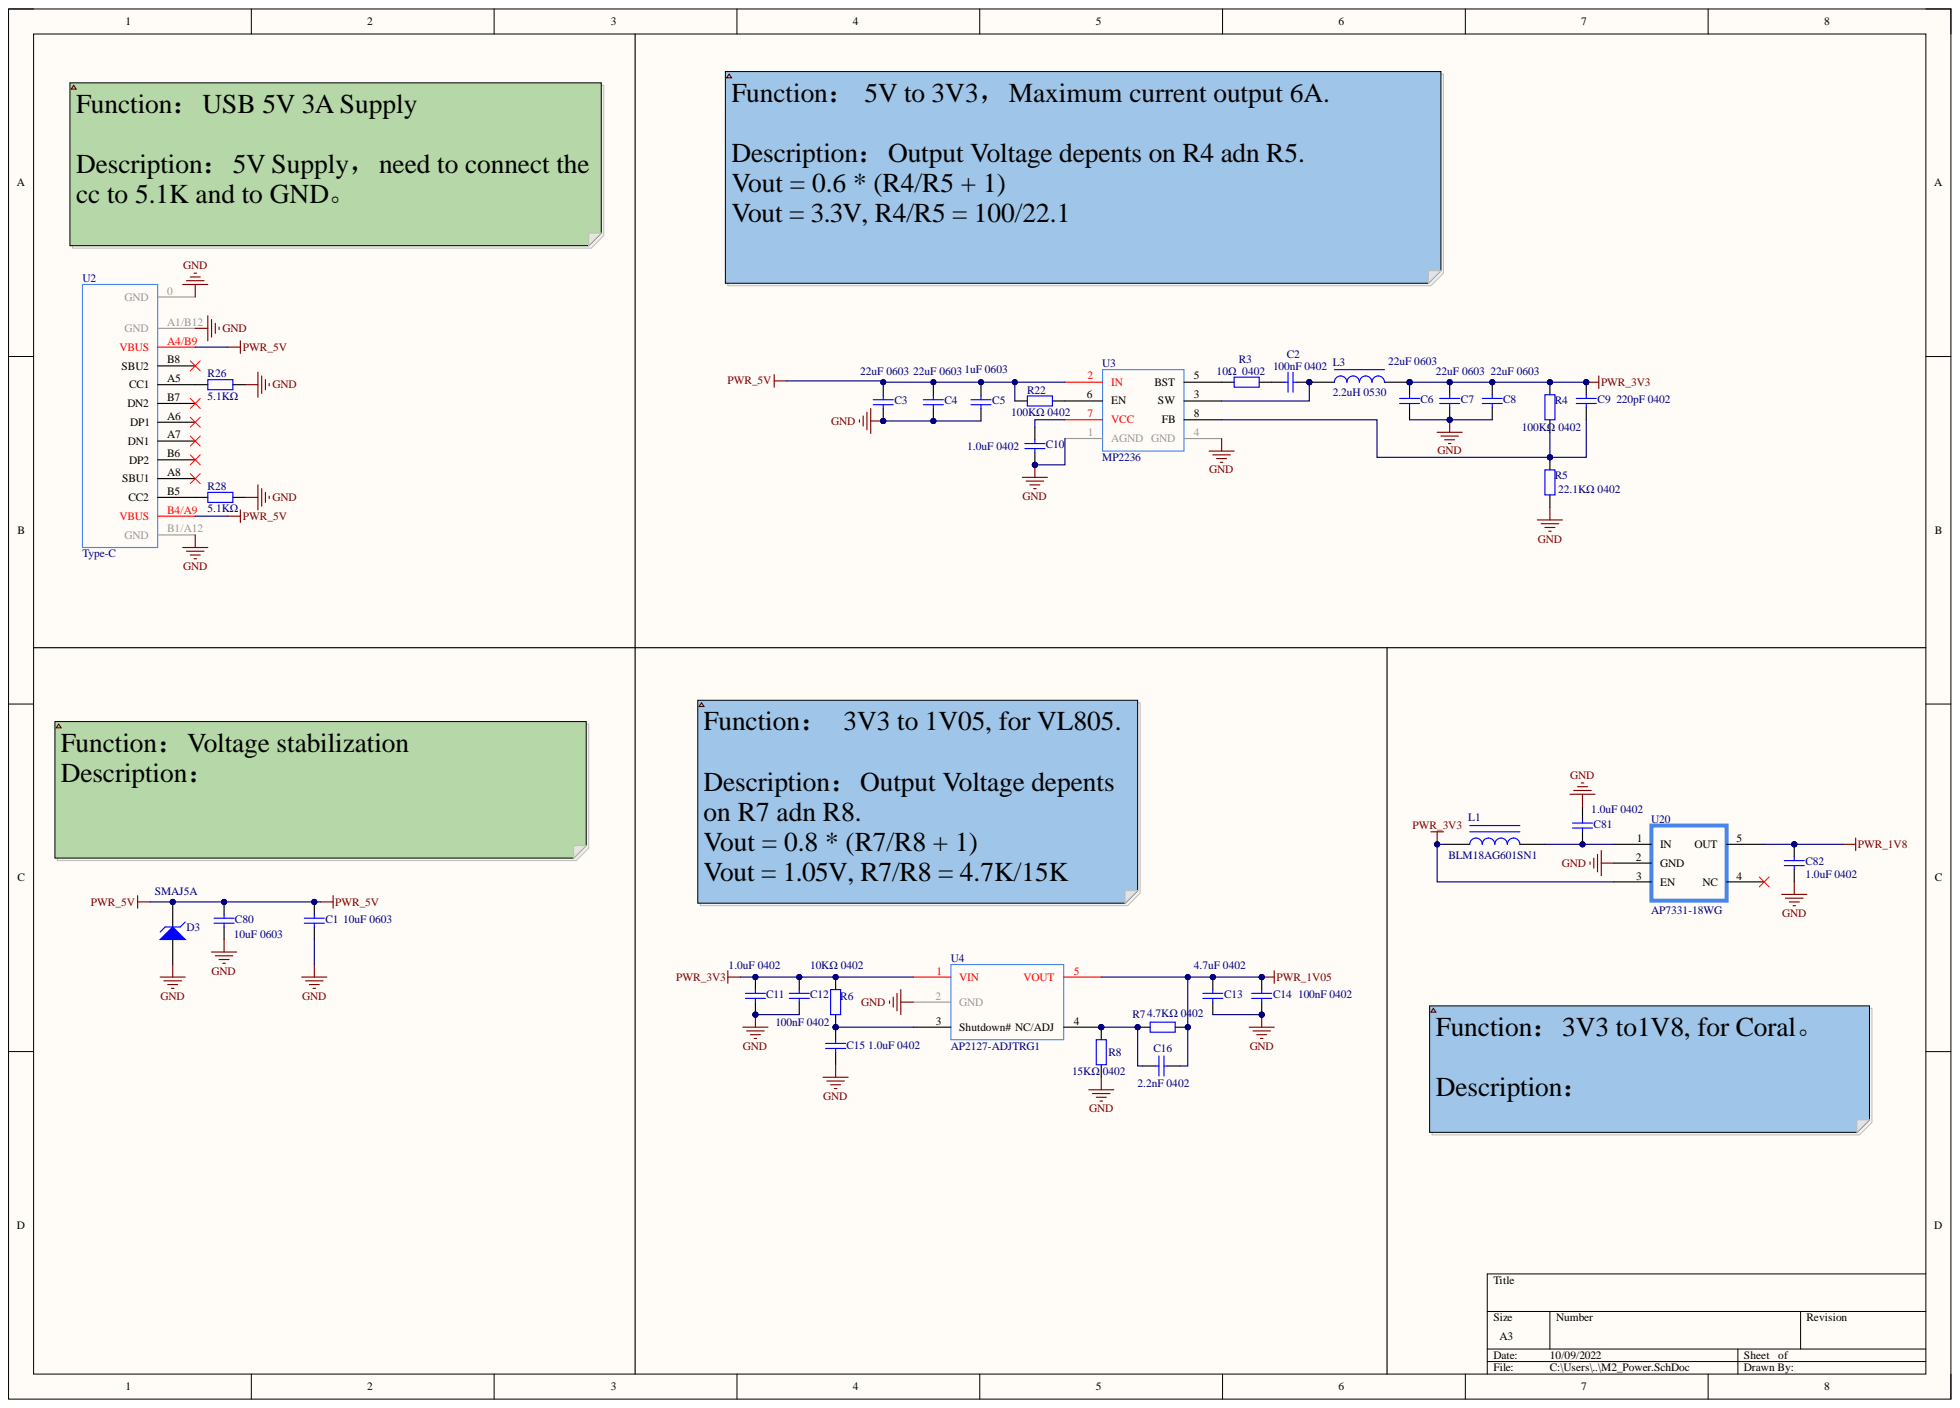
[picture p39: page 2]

Function： 5V to 3V3，Maximum current output 6A.

Description：Output Voltage depents on R4 adn R5.
Vout = 0.6 * (R4/R5 + 1)
Vout = 3.3V, R4/R5 = 100/22.1

Description：5V Supply，need to connect the
cc to 5.1K and to GND。

Description：Output Voltage depents
on R7 adn R8.
Vout = 0.8 * (R7/R8 + 1)
Vout = 1.05V, R7/R8 = 4.7K/15K

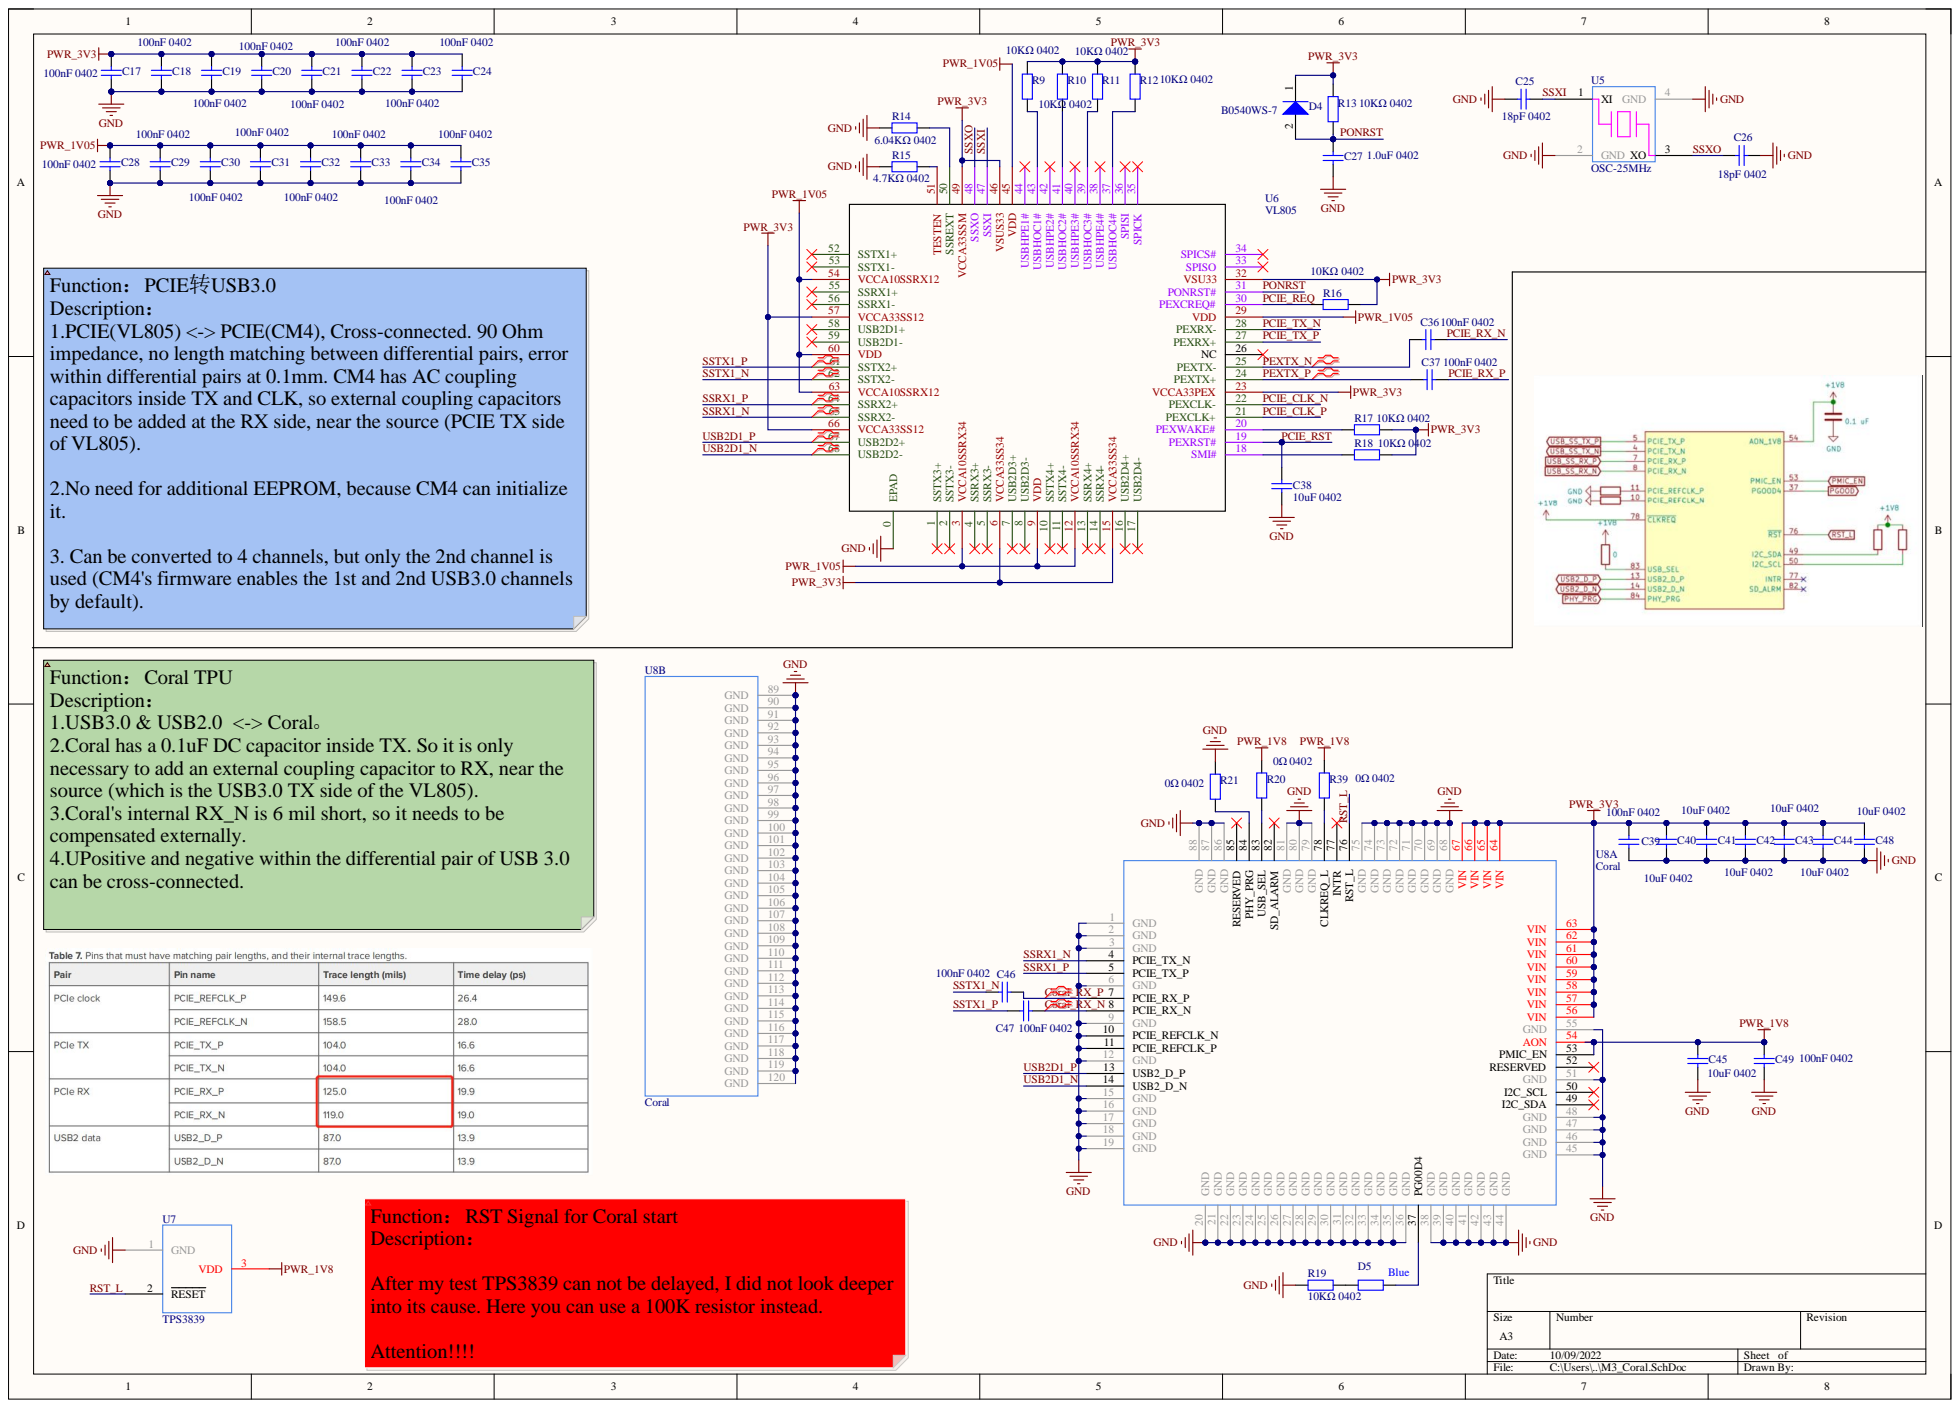
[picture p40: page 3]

Function：PCIE转USB3.0
Description：
1.PCIE(VL805) <-> PCIE(CM4), Cross-connected. 90 Ohm
impedance, no length matching between differential pairs, error
within differential pairs at 0.1mm. CM4 has AC coupling
capacitors inside TX and CLK, so external coupling capacitors
need to be added at the RX side, near the source (PCIE TX side

SSRX1+ 55 | R16
SSRX1- 56 | PCIE_REQ

SSTX2+ 61 SSTX2- 62 VCCA10SSRX12 63

SSRX2+ 64 SSRX2- 65 VCCA33SS12 66 | PCIE_CLK_N

2.No need for additional EEPROM, because CM4 can initialize

3. Can be converted to 4 channels, but only the 2nd channel is
used (CM4's firmware enables the 1st and 2nd USB3.0 channels
by default).

Function：Coral TPU
1.USB3.0 & USB2.0 <-> Coral。
2.Coral has a 0.1uF DC capacitor inside TX. So it is only
necessary to add an external coupling capacitor to RX, near the
source (which is the USB3.0 TX side of the VL805).
3.Coral's internal RX_N is 6 mil short, so it needs to be
compensated externally.

4.UPositive and negative within the differential pair of USB 3.0
can be cross-connected.

GND 44 GND 43 GND 42 GND 41 GND 40 GND 39 GND 38 PG00D4 37 GND 36 GND 35 GND 34 GND 33 GND 32 GND 31 GND 30 GND 29 GND 28 GND 27 GND 26 GND 25 GND 24 GND 23 GND 22 GND 21 GND 20

Function：RST Signal for Coral start

After my test TPS3839 can not be delayed, I did not look deeper
into its cause. Here you can use a 100K resistor instead.

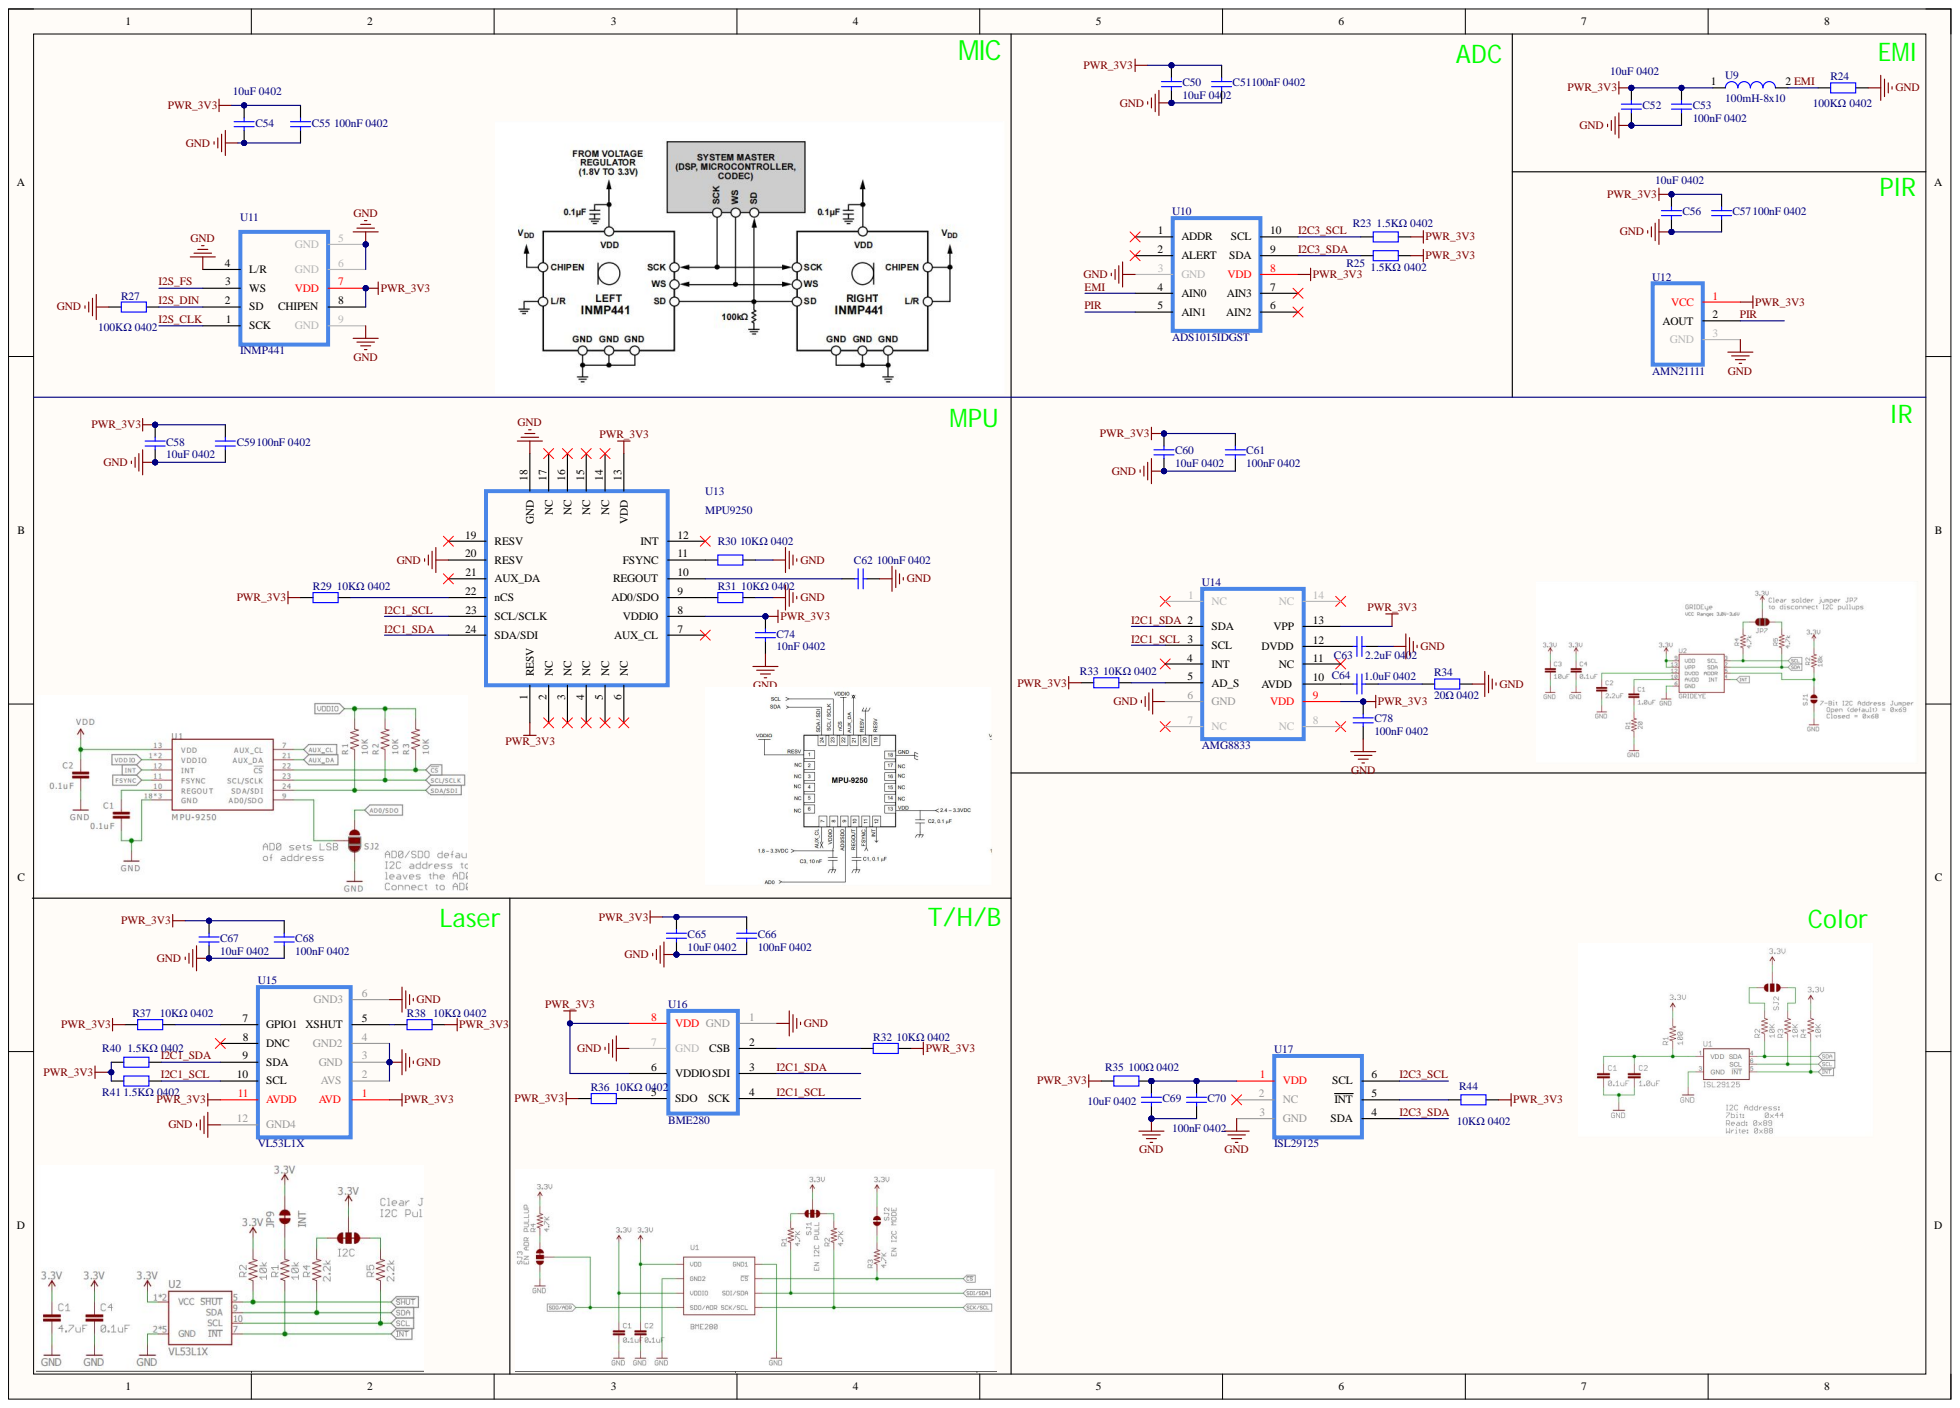
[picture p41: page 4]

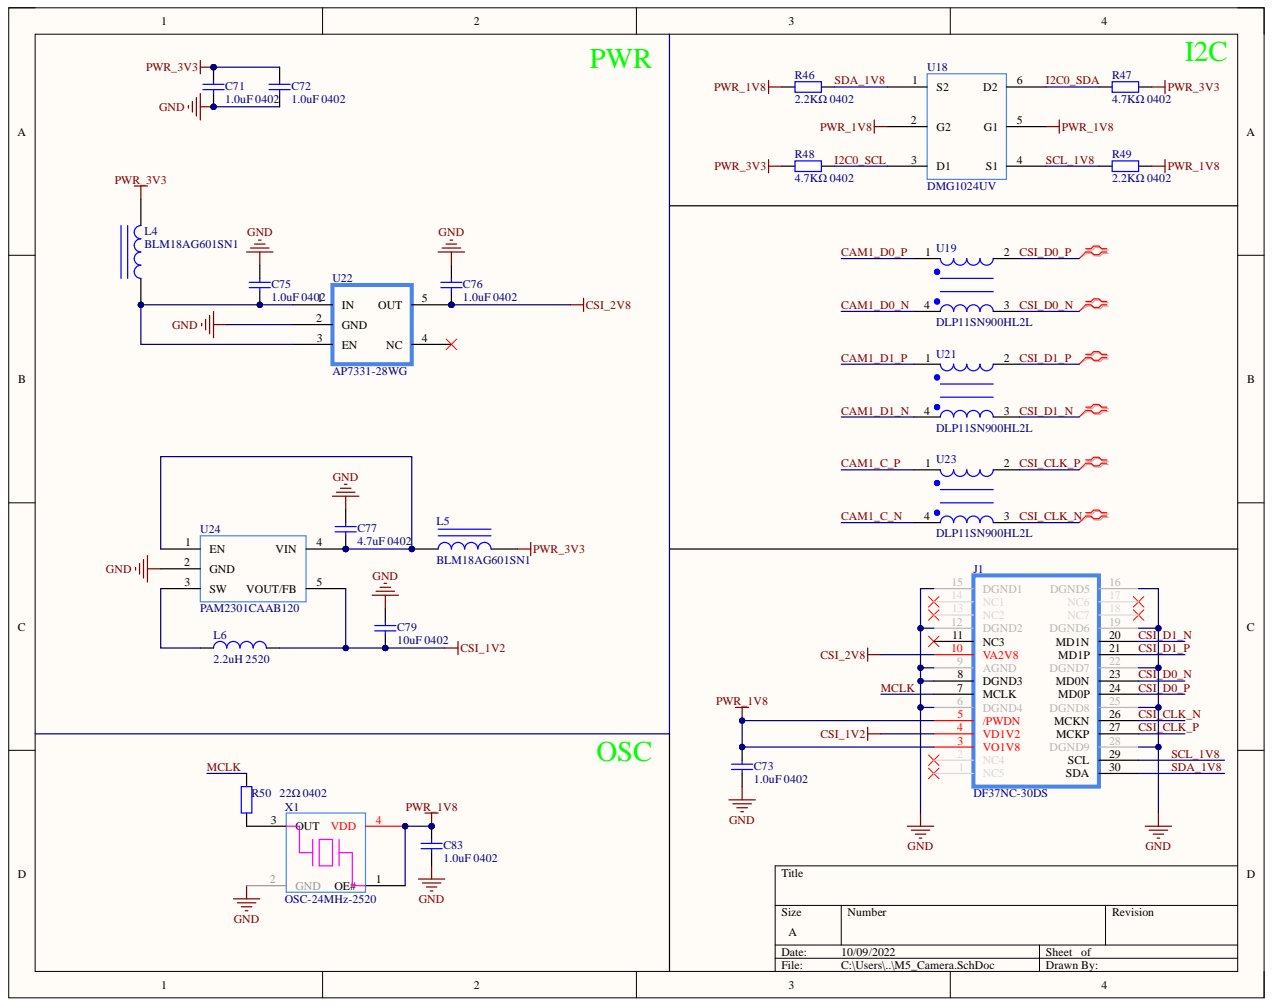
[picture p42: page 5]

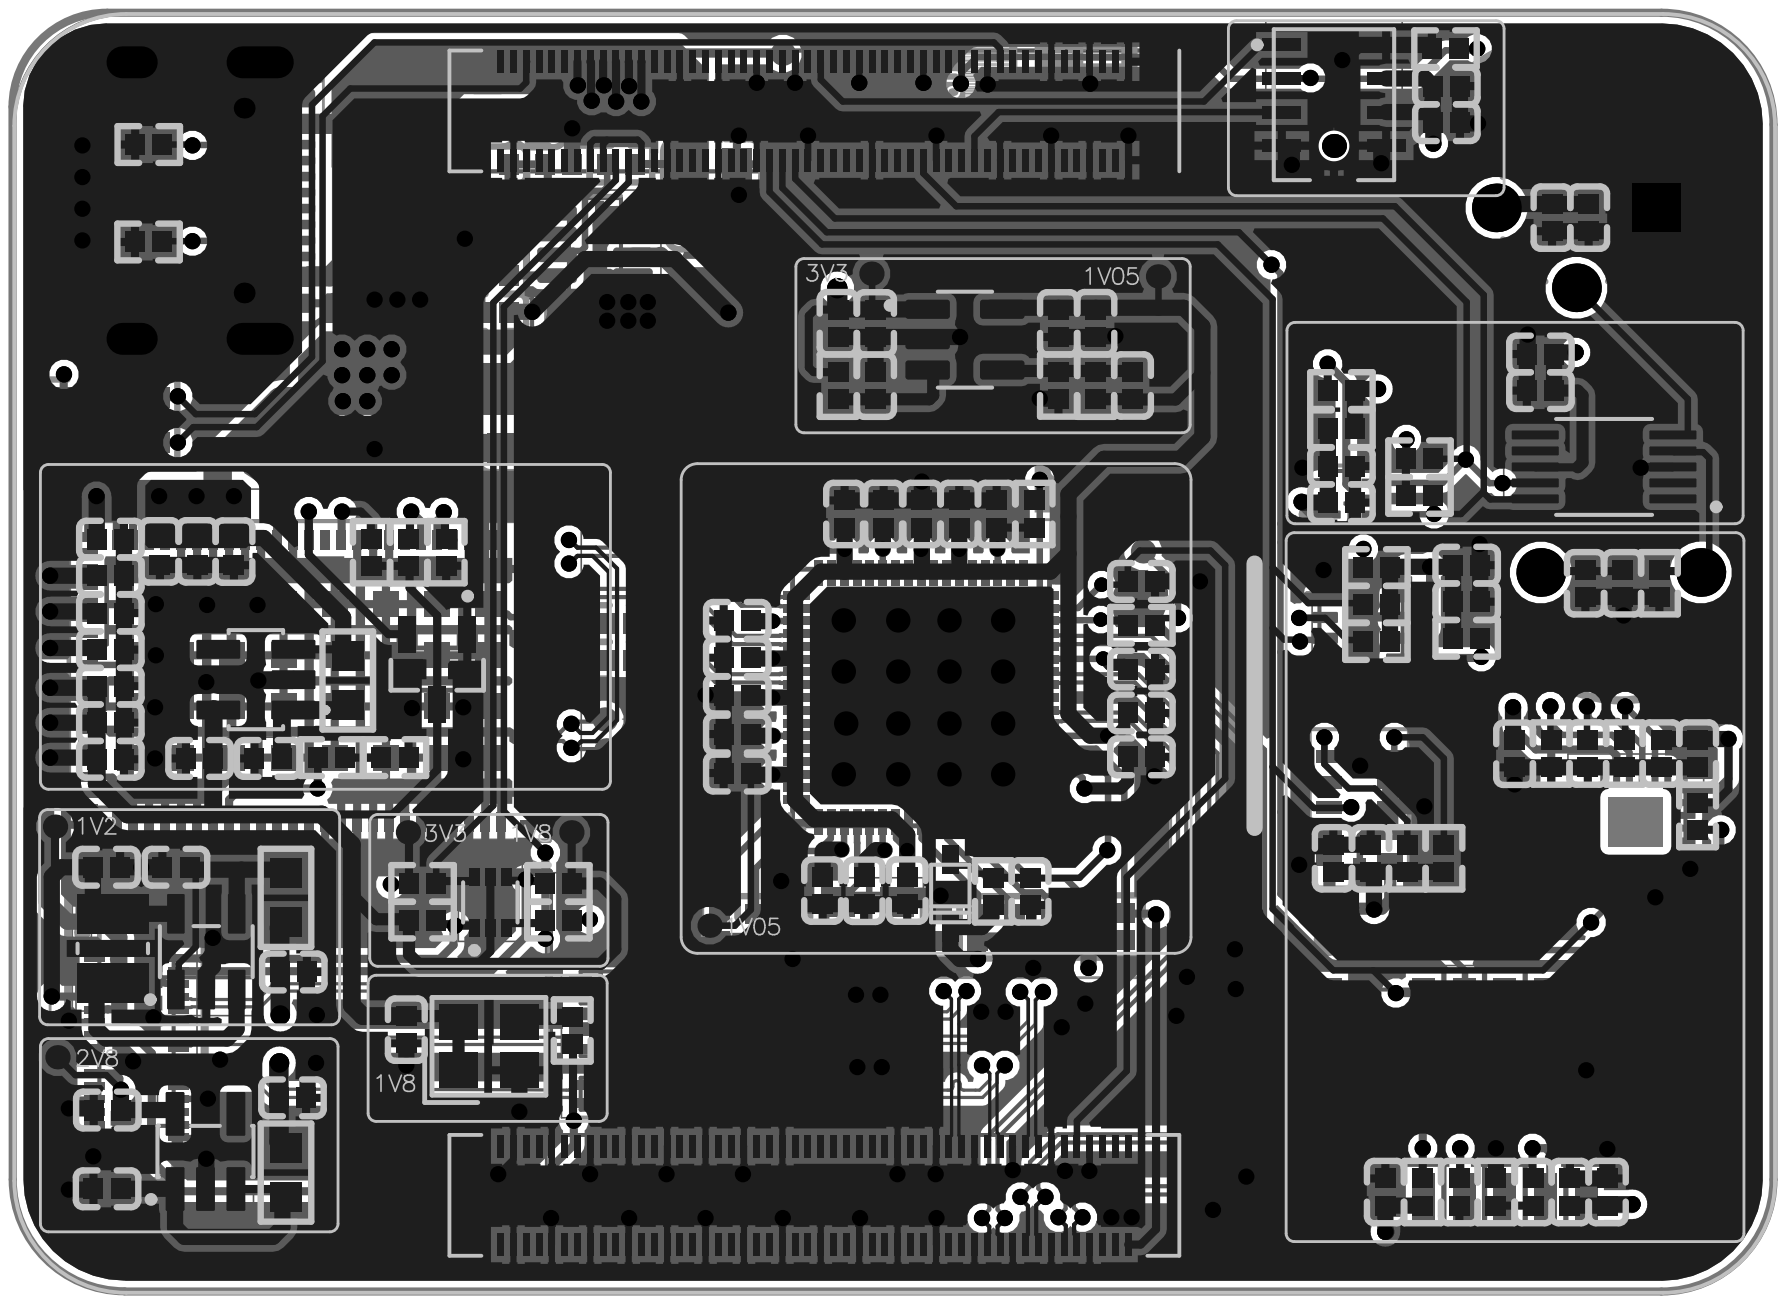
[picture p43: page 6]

Line # | Name | Description | Designator | Quantity | Manufacturer 1 | Manufacturer Part Number 1 | Manufacturer Lifecycle 1 | Supplier 1 | Supplier Part Number 1 | Supplier Unit Price 1 | Supplier Subtotal 1
| 100nF 0402 | 贴片电容 | C2, C12, C14, C17, C18, C19, C20, C21, C22, C23, C24, C28, C29, C30, C31, C32, C33, C34, C35, C36, C37, C39, C46, C47, C49, C51, C53, C55, C57, C59, C61, C62, C66, C68, C70, C78 | 36
| 10KΩ 0402 | 贴片电阻 | R6, R9, R10, R11, R12, R13, R16, R17, R18, R19, R29, R30, R31, R32, R33, R36, R37, R38, R44 | 19
| 10uF 0402 | 贴片电容 | C38, C40, C41, C42, C43, C44, C45, C48, C50, C52, C54, C56, C58, C60, C65, C67, C69, C79 | 18
| 1.0uF 0402 | 贴片电容 | C10, C11, C15, C27, C64, C71, C72, C73, C75, C76, C81, C82, C83 | 13
| 22uF 0603 | 贴片电容 | C3, C4, C6, C7, C8 | 5
| 1.5KΩ 0402 | 贴片电阻 | R23, R25, R40, R41 | 4
| 4.7KΩ 0402 | 贴片电阻 | R7, R15, R47, R48 | 4
| 100KΩ 0402 | 贴片电阻 | R4, R22, R24, R27 | 4
| 0Ω 0402 | 贴片电阻 | R20, R21, R39 | 3
| BLM18AG601SN1 | 贴片电感 | L1, L4, L5 | 3
| DLP11SN900HL2L | Camera | U19, U21, U23 | 3
| 1KΩ 0402 | 贴片电阻 | R1, R2 | 2
| 2.2KΩ 0402 | 贴片电阻 | R46, R49 | 2
| 4.7uF 0402 | 贴片电容 | C13, C77 | 2
| 5.1KΩ | 贴片电阻 | R26, R28 | 2
| 10uF 0603 | 贴片电容 | C1, C80 | 2
| 18pF 0402 | 贴片电容 | C25, C26 | 2
| 1uF 0603 | 贴片电容 | C5 | 1
| 2.2nF 0402 | 贴片电容 | C16 | 1
| 2.2uF 0402 | 贴片电容 | C63 | 1
| 2.2uH 0530 | 2.2uH 0630 | L3 | 1
| 2.2uH 2520 | 2520 | L6 | 1
| 6.04KΩ 0402 | 贴片电阻 | R14 | 1
| 10nF 0402 | 贴片电容 | C74 | 1
| 10Ω 0402 | 贴片电阻 | R3 | 1
| 15KΩ 0402 | 贴片电阻 | R8 | 1
| 20Ω 0402 | 贴片电阻 | R34 | 1
| 22Ω 0402 | 贴片电阻 | R50 | 1
| 22.1KΩ 0402 | 贴片电阻 | R5 | 1
| 100mH-8x10 | Sensor 100mH | U9 | 1
| 100Ω 0402 | 贴片电阻 | R35 | 1
| 220pF 0402 | 贴片电容 | C9 | 1
| ADS1015IDGST | ADC 12Bit 4Channel | U10 | 1
| AMG8833 | Sensor IR | U14 | 1
| AMN21111 | Sensor PIR | U12 | 1
| AP2127-ADJTRG1 | 3.3V-1.05V | U4 | 1
| AP7331-18WG | Camera 1.8V | U20 | 1
| AP7331-28WG | Camera 2.8V | U22 | 1
| B0540WS-7 | | D4 | 1
| Blue | 贴片电阻 | D5 | 1
| BME280 | Sensor T/H/B TOP View | U16 | 1
| Coral | G313-06329-00 | U8 | 1
| DF37NC-30DS | Camera Connector | J1 | 1
| DMG1024UV | Camera | U18 | 1
| Green | 贴片电阻 | D2 | 1
| INMP441 | Sensor Microphone | U11 | 1
| ISL29125 | Sensor Color | U17 | 1
| MP2236 | Vin=18, Iout=6A | U3 | 1
| MPU9250 | Sensor MPU | U13 | 1
| OSC-24MHz-2520 | 24MHz Camera | X1 | 1
| OSC-25MHz | Passive crystal oscillator | U5 | 1
| PAM2301CAAB120 | Camera 1.2V | U24 | 1
| Raspberry Pi Compute Module 4 | Raspberry Pi Compute Module 4 | U1 | 1
| Red | 贴片电阻 | D1 | 1
| SMAJ5A | TVS | D3 | 1
| TPS3839 | Delay 200 MS | U7 | 1
| Type-C | Type-C-16P | U2 | 1
| VL53L1X | Sensor Laser | U15 | 1
| VL805 | PCIe to USB3.0 | U6 | 1

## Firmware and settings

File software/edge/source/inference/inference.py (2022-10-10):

import os, sys, time
SCRIPT_DIR = os.path.dirname(os.path.abspath(__file__))
SOURCE_DIR = os.path.dirname(SCRIPT_DIR)
ROOT_DIR = os.path.dirname(SOURCE_DIR)
sys.path.append(SOURCE_DIR)
sys.path.append(ROOT_DIR)
print("# function     : real activity recognition by inference")
print("# current path :", SCRIPT_DIR)
print("# source  path :", SOURCE_DIR)
print("# root    path :", ROOT_DIR)
print("# server    ip : https://bohao.de/ecsk/datav\n")
time.sleep(5)

import drivers.mpuDriver as mpuD
import drivers.micDriver as micD
import drivers.laserDriver as laserD
import drivers.bmeDriver as bmeD
import time, statistics
import threading
import numpy as np
import multiprocessing as mp
import tflite_runtime.interpreter as tflite
import datav.datav as dv
import feature.feature as fea
import arguments as arg
import smbus

import busio
import board
import adafruit_amg88xx


# tensorflow default float32, numpy default float64
'''
@ name      : DataProcess
@ desc      : Accel Full Scale Select
@ parameter : 
@ return    :
'''
class DataProcess(mp.Process):
    def __init__(self, queue_mic, queue_acc):
        super(DataProcess, self).__init__()
        self.mpu = mpuD.MPU9250()
        self.mic, self.audio = micD.INMP441()
        self.laser = laserD.VL53L1()
        self.eye = adafruit_amg88xx.AMG88XX(busio.I2C(board.SCL, board.SDA))
        self.color = smbus.SMBus(3)
        self.queue_mic = queue_mic
        self.queue_acc = queue_acc

        # raw data placeholder
        self.mic_todo = [1 for i in range(7500)]
        self.acc_x_todo = [1 for i in range(500)]
        self.acc_y_todo = [1 for i in range(500)]
        self.acc_z_todo = [1 for i in range(500)]
        self.eye_todo = [1 for i in range(64)]
        self.laser_todo = [1 for i in range(2)]
        self.color_todo = [1 for i in range(3)]
        self.bme_todo = [1 for i in range(3)]
        self.mag_todo = [1 for i in range(4)]

    '''
        @ name      : mic_raw
        @ desc      : sample from sensor microphone INMP441 and save raw for training
        @ parameter : self
        @ return    : none
    '''
    def mic_raw(self):
        print(f"# microphone is sampling")
        while self.mic.is_active():
            stream_data = self.mic.read(arg.chunk, exception_on_overflow=False)
            mic_data = np.frombuffer(stream_data, dtype=np.int16)
            self.mic_todo = mic_data

    '''
        @ name      : mpu_acc_raw
        @ desc      : sample from acc sensor MPU9250 and save raw for training
        @ parameter : self
        @ return    : none
    '''
    def mpu_acc_raw(self):
        time.sleep(2)
        print(f"# mpu acc is sampling")
        while True:
            acc = self.mpu.readAccel()
            del self.acc_x_todo[0]
            del self.acc_y_todo[0]
            del self.acc_z_todo[0]
            self.acc_x_todo.append(acc['x'])
            self.acc_y_todo.append(acc['y'])
            self.acc_z_todo.append(acc['z'])
            time.sleep(0.0006)

    def mpu_mag_raw(self):
        time.sleep(2)
        print(f"# mpu mag is sampling")
        last_mag = 0
        while True:
            mag = []
            for i in range(10):
                magv = self.mpu.readMagnet()
                mag.append(magv['x'])
                time.sleep(0.04)
            mag = statistics.mean(mag)
            if mag - last_mag > 2:
                #print('up', mag-last_mag)
                self.mag_todo[0] = 2
            elif mag - last_mag < -2:
                self.mag_todo[0] = 1
                #print('down', mag-last_mag)
            else:
                self.mag_todo[0] = 0
                #print('noupnodown', mag-last_mag)
            last_mag = mag
            self.mag_todo[1] = magv['x']
            self.mag_todo[2] = magv['y']
            self.mag_todo[3] = magv['z']

    '''
        @ name      : laser
        @ desc      : sample from distance sensor VL53L1X and save raw for training
        @ parameter : self
        @ return    : none
    '''
    def laser_raw(self):
        last_distance = 0
        while self.laser.check_for_data_ready():
            distance = []
            for i in range(10):
                distance.append(self.laser.get_distance()/10)
                time.sleep(0.04)
            distance = statistics.mean(distance)
            if last_distance - distance > 0.2:
                self.laser_todo[0] = 0
            elif last_distance - distance < -0.2:
                self.laser_todo[0] = 2
            else:
                self.laser_todo[0] = 1
            last_distance = distance
            self.laser_todo[1] = distance
        self.laser.stop_ranging()


    def eye_raw(self):
        time.sleep(2)
        print(f"# eye is sampling")
        while True:
            eye = []
            for row in self.eye.pixels:
                for i in range(8):
                    eye.append(row[7-i]+20)
            self.eye_todo = eye
            time.sleep(0.5)

    def color_raw(self):
        self.color.write_byte_data(0x44, 0x01, 0x0D)
        time.sleep(2)
        print(f"# color is sampling")
        while True:
            data = self.color.read_i2c_block_data(0x44, 0x09, 6)
            time.sleep(0.5)
            # Convert the data
            self.color_todo[0] = data[3] * 256 + data[2]
            self.color_todo[1] = data[1] * 256 + data[0]
            self.color_todo[2] = data[5] * 256 + data[4]

    def bme_raw(self):
        time.sleep(2)
        print(f"# color is sampling")
        while True:
            temperature, pressure, humidity = bmeD.readBME280All()
            time.sleep(0.5)
            self.bme_todo[0] = temperature
            self.bme_todo[1] = humidity
            self.bme_todo[2] = pressure/100


    def run(self):
        try:
            print("# data process id : ", os.getpid())
            threads = []
            t1 = threading.Thread(target=self.mic_raw)
            threads.append(t1)
            t2 = threading.Thread(target=self.mpu_acc_raw)
            threads.append(t2)
            t3 = threading.Thread(target=self.eye_raw)
            threads.append(t3)
            t4 = threading.Thread(target=self.laser_raw)
            threads.append(t4)
            t5 = threading.Thread(target=self.color_raw)
            threads.append(t5)
            t6 = threading.Thread(target=self.bme_raw)
            threads.append(t6)
            t7 = threading.Thread(target=self.mpu_mag_raw)
            threads.append(t7)
            for t in threads:
                t.start()
            while True:
                if not self.queue_mic.full():
                    data = {'mic': self.mic_todo}
                    self.queue_mic.put(data)
                if not self.queue_acc.full():
                    data = {'acc_x': self.acc_x_todo,
                            'acc_y': self.acc_y_todo,
                            'acc_z': self.acc_z_todo,
                            'laser': self.laser_todo,
                            'eye'  : self.eye_todo,
                            'color': self.color_todo,
                            'bme': self.bme_todo,
                            'mag': self.mag_todo
                            }
                    self.queue_acc.put(data)
                time.sleep(0.5)
        except KeyboardInterrupt:
            print('# DATAP: Is KeyboardInterrupt')
            self.mic.stop_stream()
            self.mic.close()
            self.audio.terminate()
            self.laser.stop_ranging()
            sys.exit()


class MicFeatureProcess(mp.Process):
    def __init__(self, queue_in, queue_out):
        super(MicFeatureProcess, self).__init__()
        self.queue_in = queue_in
        self.queue_out = queue_out

    def run(self):
        print("# mic feature process id : ", os.getpid())
        while True:
            if not self.queue_in.empty():
                result = self.queue_in.get()
                mic_feature = fea.micfeature(result['mic'])
                self.queue_out.put(mic_feature)


class AccFeatureProcess(mp.Process):
    def __init__(self, queue_in, queue_out):
        super(AccFeatureProcess, self).__init__()
        self.queue_in = queue_in
        self.queue_out = queue_out

    def run(self):
        print("# acc feature process id : ", os.getpid())
        while True:
            if not self.queue_in.empty():
                result = self.queue_in.get()
                acc_x_feature, acc_y_feature, acc_z_feature = fea.accfreature(result['acc_x'], result['acc_y'], result['acc_z'])
                laser_feature = result['laser']
                data = {'acc_x': acc_x_feature,
                        'acc_y': acc_y_feature,
                        'acc_z': acc_z_feature,
                        'laser': laser_feature,
                        'eye'  : result['eye'],
                        'color': result['color'],
                        'bme': result['bme'],
                        'mag': result['mag']
                        }
                self.queue_out.put(data)


class RecoModelProcess(mp.Process):
    def __init__(self, queue_mic_fea, queue_acc_fea):
        super(RecoModelProcess, self).__init__()
        self.queue_mic_fea = queue_mic_fea
        self.queue_acc_fea = queue_acc_fea


        # feature placeholder
        self.mic_feature = np.random.random((60, 66))
        self.acc_x_feature = np.random.random((60, 8))
        self.acc_y_feature = np.random.random((60, 8))
        self.acc_z_feature = np.random.random((60, 8))
        self.laser_feature = np.random.random((60, 1))

    '''
         @ name      : mpu_gyr_raw
         @ desc      : sample from gyr sensor MPU9250 and save raw for training
         @ parameter : self
         @ return    : none
     '''


    def run(self):
        print("# model process id : ", os.getpid())
        spin_interpreter = tflite.Interpreter(model_path=f"{ROOT_DIR}/models/inference/spin.tflite")
        spin_interpreter.allocate_tensors()
        #print(spin_interpreter.get_output_details())

        input_details = spin_interpreter.get_input_details()
        #print(spin_interpreter.get_input_details())
        input_index = input_details[0]['index']
        # 0-fin: 96, 1-mic: 58, 2-x:68, 3-y:78, 4-z:88, 5-laser:93

        while True:
            pred_resutl = []
            if not self.queue_mic_fea.empty():
                result = self.queue_mic_fea.get()
                self.mic_feature = result
            if not self.queue_acc_fea.empty():
                result = self.queue_acc_fea.get()
                self.acc_x_feature = result['acc_x']
                self.acc_y_feature = result['acc_y']
                self.acc_z_feature = result['acc_z']
                self.laser_feature = [result['laser'][0] for i in range(60)]
                laser_data = result['laser'][1]
                eye_data = result['eye']
                color_data = result['color']
                bme_data = result['bme']
                mag_data = result['mag']
                merge_feature = np.column_stack((self.mic_feature,
                                                 self.acc_x_feature,
                                                 self.acc_y_feature,
                                                 self.acc_z_feature,
                                                 self.laser_feature)).astype(dtype=np.float32).reshape(1, 60, 91, 1)

                spin_interpreter.set_tensor(input_index, merge_feature)
                spin_interpreter.invoke()
                spin_output = spin_interpreter.get_tensor(96)
                if spin_output > 0.2:
                    pred_resutl.append('spin')
                    # print(f"spin       : Y")
                if result['laser'][0] == 2:
                    pred_resutl.append('upward')
                    #print(f"upward     : Y")
                if result['laser'][0] == 0:
                    pred_resutl.append('downward')
                    # print(f"downward   : Y")

                # 0.18s
                dv.featurev(self.mic_feature, self.acc_x_feature, self.acc_y_feature, self.acc_z_feature,self.laser_feature[0], pred_resutl, laser_data, eye_data, color_data, bme_data, mag_data)

if __name__ == "__main__":
    try:
        print("main process id:", os.getpid())
        queue_mic_raw = mp.Queue()
        queue_acc_raw = mp.Queue()
        queue_mic_fea = mp.Queue()
        queue_acc_fea = mp.Queue()
        d = DataProcess(queue_mic_raw, queue_acc_raw)
        m = MicFeatureProcess(queue_mic_raw, queue_mic_fea)
        a = AccFeatureProcess(queue_acc_raw, queue_acc_fea)
        r = RecoModelProcess(queue_mic_fea, queue_acc_fea)
        d.start()
        m.start()
        a.start()
        r.start()
    finally:
        time.sleep(3)
        print("\n# please type ctrl+c to stop program")

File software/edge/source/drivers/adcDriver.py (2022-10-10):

import logging
import time
import smbus

# Register and other configuration values:
ADS1x15_DEFAULT_ADDRESS        = 0x48
ADS1x15_POINTER_CONVERSION     = 0x00
ADS1x15_POINTER_CONFIG         = 0x01
ADS1x15_POINTER_LOW_THRESHOLD  = 0x02
ADS1x15_POINTER_HIGH_THRESHOLD = 0x03
ADS1x15_CONFIG_OS_SINGLE       = 0x8000
ADS1x15_CONFIG_MUX_OFFSET      = 12
# Maping of gain values to config register values.
ADS1x15_CONFIG_GAIN = {
    2/3: 0x0000,
    1:   0x0200,
    2:   0x0400,
    4:   0x0600,
    8:   0x0800,
    16:  0x0A00
}
ADS1x15_CONFIG_MODE_CONTINUOUS  = 0x0000
ADS1x15_CONFIG_MODE_SINGLE      = 0x0100
# Mapping of data/sample rate to config register values for ADS1015 (faster).
ADS1015_CONFIG_DR = {
    128:   0x0000,
    250:   0x0020,
    490:   0x0040,
    920:   0x0060,
    1600:  0x0080,
    2400:  0x00A0,
    3300:  0x00C0
}
ADS1x15_CONFIG_COMP_WINDOW      = 0x0010
ADS1x15_CONFIG_COMP_ACTIVE_HIGH = 0x0008
ADS1x15_CONFIG_COMP_LATCHING    = 0x0004
ADS1x15_CONFIG_COMP_QUE = {
    1: 0x0000,
    2: 0x0001,
    4: 0x0002
}
ADS1x15_CONFIG_COMP_QUE_DISABLE = 0x0003

class Device(object):
    def __init__(self, address, busnum=3, i2c_interface=None):
        self._address = address
        self._bus = smbus.SMBus(busnum)
        self._logger = logging.getLogger('Adafruit_I2C.Device.Bus.{0}.Address.{1:#0X}' \
                                .format(busnum, address))

    def writeRaw8(self, value):
        """Write an 8-bit value on the bus (without register)."""
        value = value & 0xFF
        self._bus.write_byte(self._address, value)
        self._logger.debug("Wrote 0x%02X",
                     value)

    def write8(self, register, value):
        """Write an 8-bit value to the specified register."""
        value = value & 0xFF
        self._bus.write_byte_data(self._address, register, value)
        self._logger.debug("Wrote 0x%02X to register 0x%02X",
                     value, register)

    def write16(self, register, value):
        """Write a 16-bit value to the specified register."""
        value = value & 0xFFFF
        self._bus.write_word_data(self._address, register, value)
        self._logger.debug("Wrote 0x%04X to register pair 0x%02X, 0x%02X",
                     value, register, register+1)

    def writeList(self, register, data):
        """Write bytes to the specified register."""
        self._bus.write_i2c_block_data(self._address, register, data)
        self._logger.debug("Wrote to register 0x%02X: %s",
                     register, data)

    def readList(self, register, length):
        """Read a length number of bytes from the specified register.  Results
        will be returned as a bytearray."""
        results = self._bus.read_i2c_block_data(self._address, register, length)
        self._logger.debug("Read the following from register 0x%02X: %s",
                     register, results)
        return results

    def readRaw8(self):
        """Read an 8-bit value on the bus (without register)."""
        result = self._bus.read_byte(self._address) & 0xFF
        self._logger.debug("Read 0x%02X",
                    result)
        return result

    def readU8(self, register):
        """Read an unsigned byte from the specified register."""
        result = self._bus.read_byte_data(self._address, register) & 0xFF
        self._logger.debug("Read 0x%02X from register 0x%02X",
                     result, register)
        return result

    def readS8(self, register):
        """Read a signed byte from the specified register."""
        result = self.readU8(register)
        if result > 127:
            result -= 256
        return result

    def readU16(self, register, little_endian=True):
        """Read an unsigned 16-bit value from the specified register, with the
        specified endianness (default little endian, or least significant byte
        first)."""
        result = self._bus.read_word_data(self._address,register) & 0xFFFF
        self._logger.debug("Read 0x%04X from register pair 0x%02X, 0x%02X",
                           result, register, register+1)
        # Swap bytes if using big endian because read_word_data assumes little
        # endian on ARM (little endian) systems.
        if not little_endian:
            result = ((result << 8) & 0xFF00) + (result >> 8)
        return result

    def readS16(self, register, little_endian=True):
        """Read a signed 16-bit value from the specified register, with the
        specified endianness (default little endian, or least significant byte
        first)."""
        result = self.readU16(register, little_endian)
        if result > 32767:
            result -= 65536
        return result

    def readU16LE(self, register):
        """Read an unsigned 16-bit value from the specified register, in little
        endian byte order."""
        return self.readU16(register, little_endian=True)

    def readU16BE(self, register):
        """Read an unsigned 16-bit value from the specified register, in big
        endian byte order."""
        return self.readU16(register, little_endian=False)

    def readS16LE(self, register):
        """Read a signed 16-bit value from the specified register, in little
        endian byte order."""
        return self.readS16(register, little_endian=True)

    def readS16BE(self, register):
        """Read a signed 16-bit value from the specified register, in big
        endian byte order."""
        return self.readS16(register, little_endian=False)
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

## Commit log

2022-09-27 edge and server
    [M1_CM4.SchDoc, M2_Power.SchDoc, M3_Coral.SchDoc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]
2022-10-04 modify some driver
2022-10-10 all sensors work well
    [Mars.PrjPcb]
2022-10-10 uploaded digital twin and data visualization source code
    [350.obj, cnc.obj, cnc1.obj]
